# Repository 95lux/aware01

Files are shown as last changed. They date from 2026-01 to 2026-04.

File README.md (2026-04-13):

# Aarebot

> **Dynamic realtime stereo sampler for Eurorack modular synthesizer - STM32H7**

---

Aarebot is a dynamic realtime sampler built as a Eurorack module. At its core is a stereo tape-style engine with a hot-swapping record/playback buffer - this enables to record and play simultaneously.
Slicing markers can be added on the fly, and processing through an onboard effects chain.

Samplerate decimation trades fidelity for buffer length.
A Schroeder reverb implementation reaching from spacious room to sharp metallic resonance ringing depending on the XY effect mapping.

More DSP FX and taillred XY mapping is on the way and will turn Aarebot into an IDM LOFI crunch machine.

---
<p align="center">
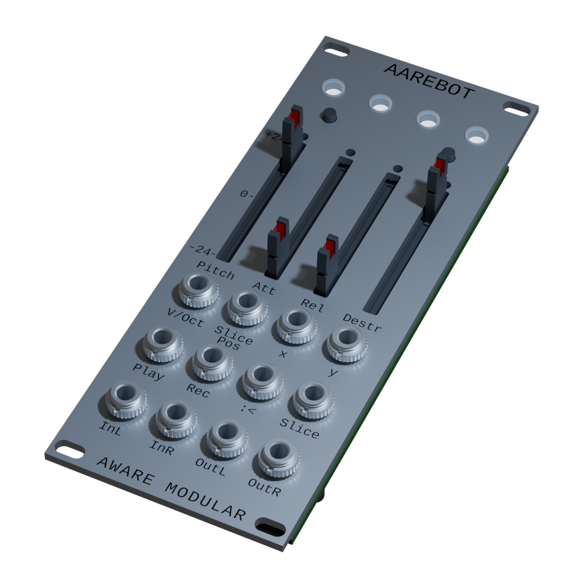
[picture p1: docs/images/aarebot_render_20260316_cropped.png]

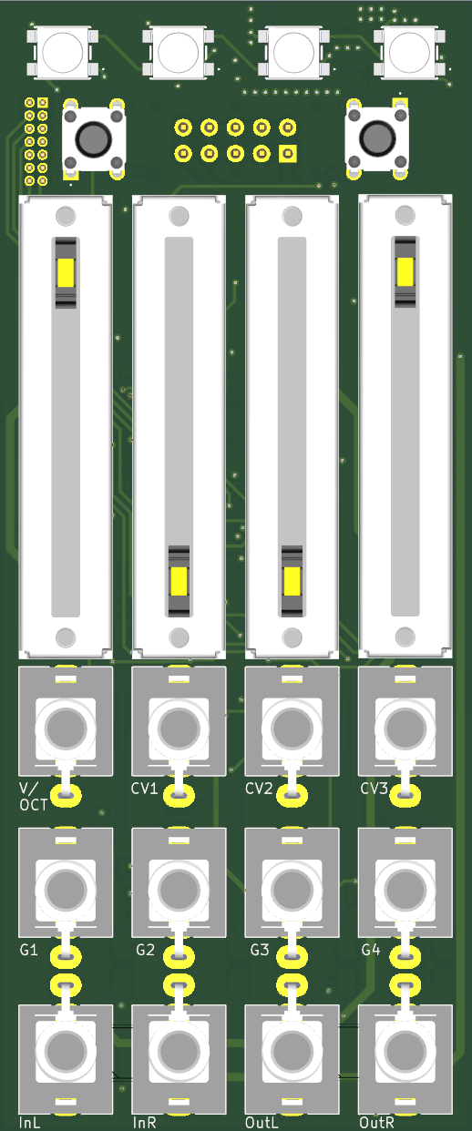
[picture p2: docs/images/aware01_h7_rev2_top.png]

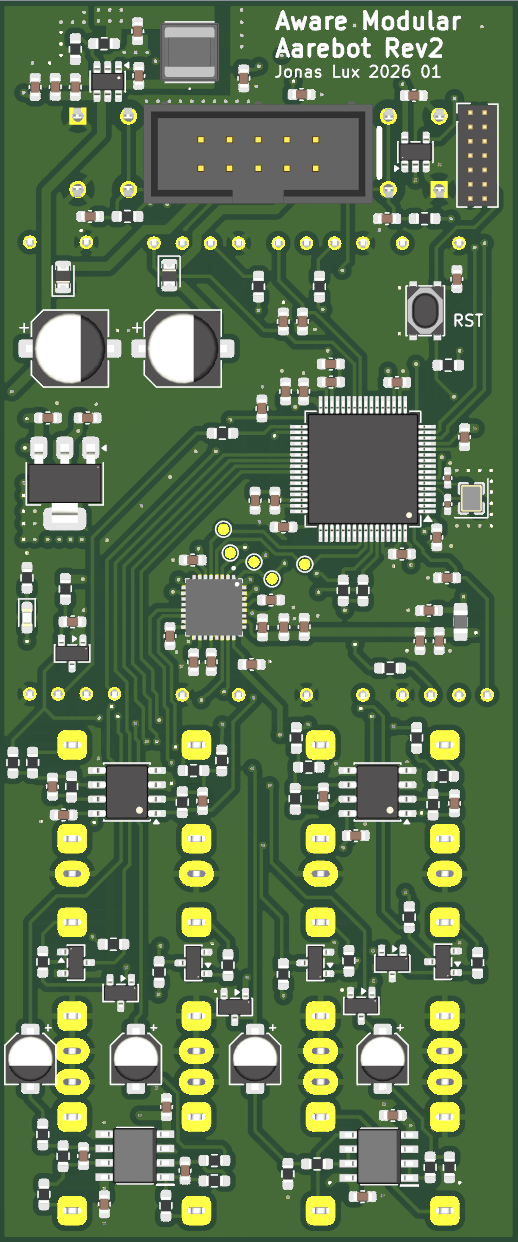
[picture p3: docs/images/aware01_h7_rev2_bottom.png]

</p>

## Features

### Audio Engine
- Stereo hot-swap record/playback buffer
- Realtime sample slicing with manual slice marker placement
- Hermite interpolation for smooth pitch shifting (±24 semitones)
- V/Oct pitch tracking (−1.5 V to +5 V)
- Samplerate decimation for extended recording time and lo-fi texture
- Nonlinear exciter
- Schroeder reverb with prime-length delay lines and scalable room size

### Control
| Interface | Function |
|---|---|
| Pot 1 | Base pitch (±24 semitones) |
| Pot 2 | Envelope attack |
| Pot 3 | Envelope decay / release |
| Pot 4 | Recording decimation |
| V/Oct | Pitch CV input |
| CV 2 | XY effect plane - X axis |
| CV 3 | XY effect plane - Y axis |
| Gate 1 | Record |
| Gate 2 | Play |
| Gate 3 | *(unassigned)* |
| Gate 4 | Set slice marker |

### Hardware
- STM32H7 MCU
- Custom I2C audio codec driver
- 4x WS2812 RGB LEDs for visual feedback
- ADC calibration with 2-point and piecewise CV calibration
- Full KiCad schematic and PCB design
- SPICE simulations for analog input/output stages

---

## Repository Structure

```
├── firmware/                 STM32CubeMX project and C source
|   ├── Aware                 Main firmware implementation
|   └── Src                   CubeMX generated src files
├── hardware/
│   ├── aware01_h7_rev2_0/    KiCad schematic and PCB
│   └── simulation/           SPICE simulations for analog stages
└── docs/
    ├── images/               PCB renders and oscilloscope captures
    ├── ba/                   Bachelor thesis
    │   ├── latex/            LaTeX source files
    │   ├── images/           Figures and plots
    │   ├── diagrams/         DrawIO block diagrams
    │   └── scripts/          Python scripts for analysis and plots
    └── project_management/   Project planning documents
        ├── lastenheft.tex    Requirements specification
        ├── pflichtenheft.tex Functional specification
        └── projectplan.tex   Project plan
```

---

## Building

### Dependencies

| Tool | Arch | Debian/Ubuntu |
|---|---|---|
| ARM cross-compiler | `arm-none-eabi-gcc` | `gcc-arm-none-eabi` |
| ARM newlib | `arm-none-eabi-newlib` | `libnewlib-arm-none-eabi` |
| CMake ≥ 3.22 | `cmake` | `cmake` |
| Ninja | `ninja` | `ninja-build` |

### Compile

```sh
cd firmware

# Configure + build (Debug)
cmake --preset Debug
cmake --build --preset Debug

# Configure + build (Release)
cmake --preset Release
cmake --build --preset Release
```

The output ELF is at `firmware/build/Debug/firmware.elf`.

### Flash

Requires an ST-Link probe. Either `st-flash` (stlink) or `openocd` can be used.

**openocd** (recommended; works directly with ELF):

```sh
openocd -f interface/stlink.cfg -f target/stm32h7x.cfg \
  -c "program firmware/build/Debug/firmware.elf verify reset exit"
```

**st-flash** (requires converting ELF to binary first):

```sh
arm-none-eabi-objcopy -O binary \
  firmware/build/Debug/firmware.elf \
  firmware/build/Debug/firmware.bin

st-flash write firmware/build/Debug/firmware.bin 0x8000000
```

| Tool | Arch | Debian/Ubuntu |
|---|---|---|
| openocd | `openocd` | `openocd` |
| st-flash | `stlink` | `stlink-tools` |

---

## Hardware

Designed in KiCad. The hardware directory contains the full schematic, PCB layout, and SPICE simulations for the analog input and output conditioning stages.

### KiCad Library

Opening the KiCad project requires the custom component library. Clone it alongside this repo:

```sh
git clone https://github.com/95lux/kicad_library
```

Then add it as a global library in KiCad: **Preferences → Manage Symbol Libraries** (and **Manage Footprint Libraries**), pointing to the cloned directory.

---

## Specifications

### Audio
| Parameter | Value |
|---|---|
| Sample rate | 48 kHz |
| Bit depth | 16-bit |
| Recording buffer | 2.5 s (stereo) |
| End-to-end latency | ~1.9 ms |
| Audio codec | TLV320AIC3204 |

### Hardware
| Parameter | Value |
|---|---|
| MCU | STM32H7A3RITx (Cortex-M7, 280 MHz) |
| Form factor | 10 HP, 3U Eurorack |
| Audio I/O levels | ±5 V |
| CV input range | ±10 V |
| V/Oct range | −1.5 V to +5 V |
| Power (+12V) | ~80 mA idle, ~140 mA peak |
| Power (−12V) | ~20 mA |

---

## License

| Component | License |
|---|---|
| Firmware / software | [GPL-3.0](LICENSE) |
| Hardware (schematics, PCB, SPICE) | [CERN OHL-S v2](LICENSE-CERN-OHL-S) |
| Thesis / documentation | [CC BY 4.0](LICENSE-CC-BY) |

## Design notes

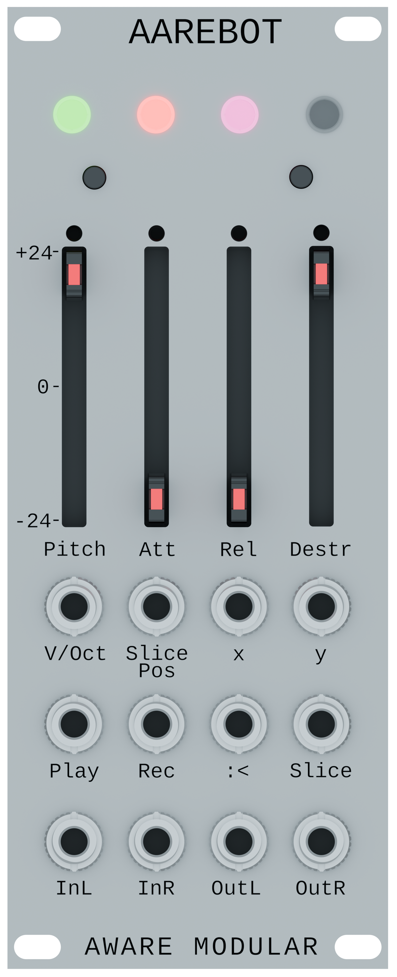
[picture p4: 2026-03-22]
hardware/panel_design/blender_render/aarebot_render_topdown_20260321.png

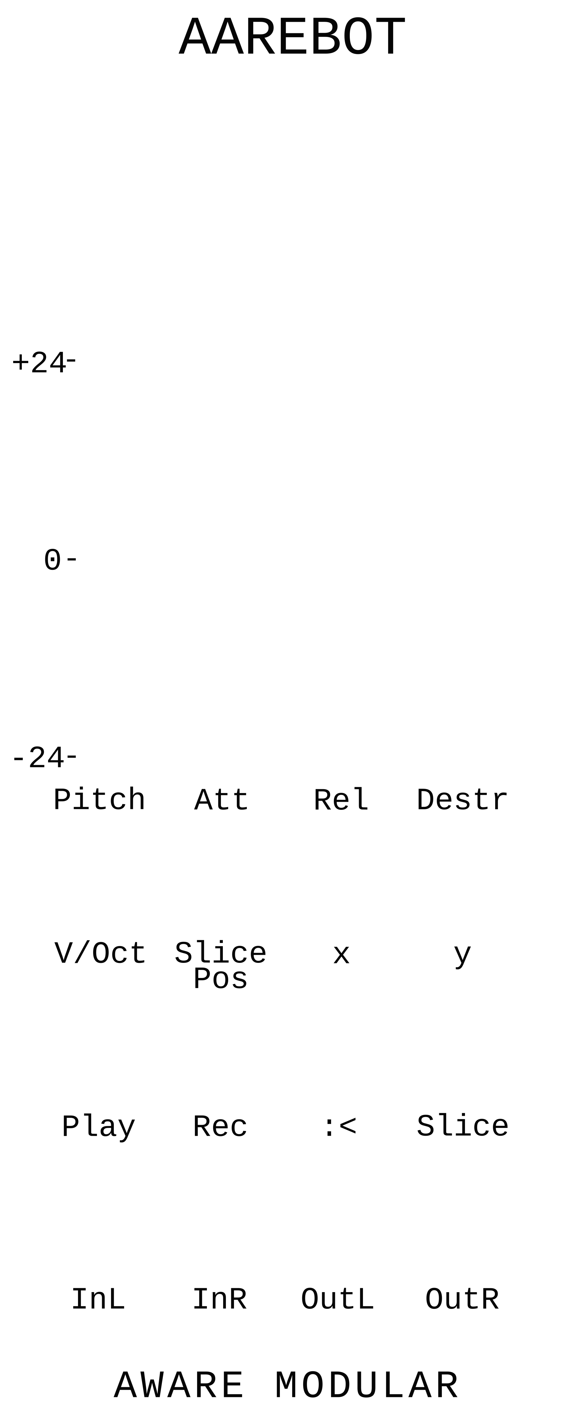
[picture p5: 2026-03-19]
hardware/panel_design/design/export/panel_font_only_texture.png

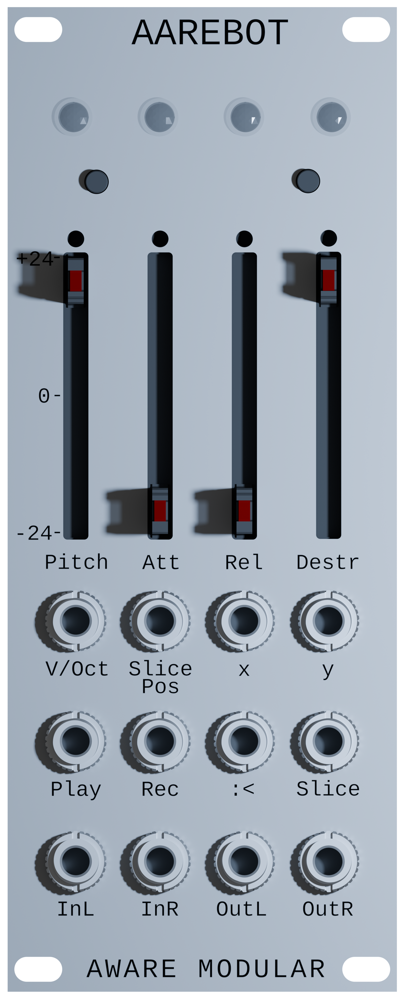
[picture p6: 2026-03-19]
hardware/panel_design/blender_render/aarebot_render_topdown_20260316.png

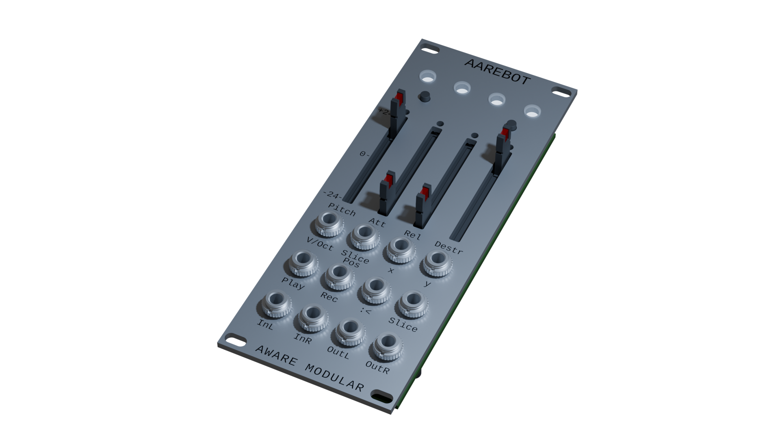
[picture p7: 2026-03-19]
hardware/panel_design/blender_render/aarebot_render_20260316.png

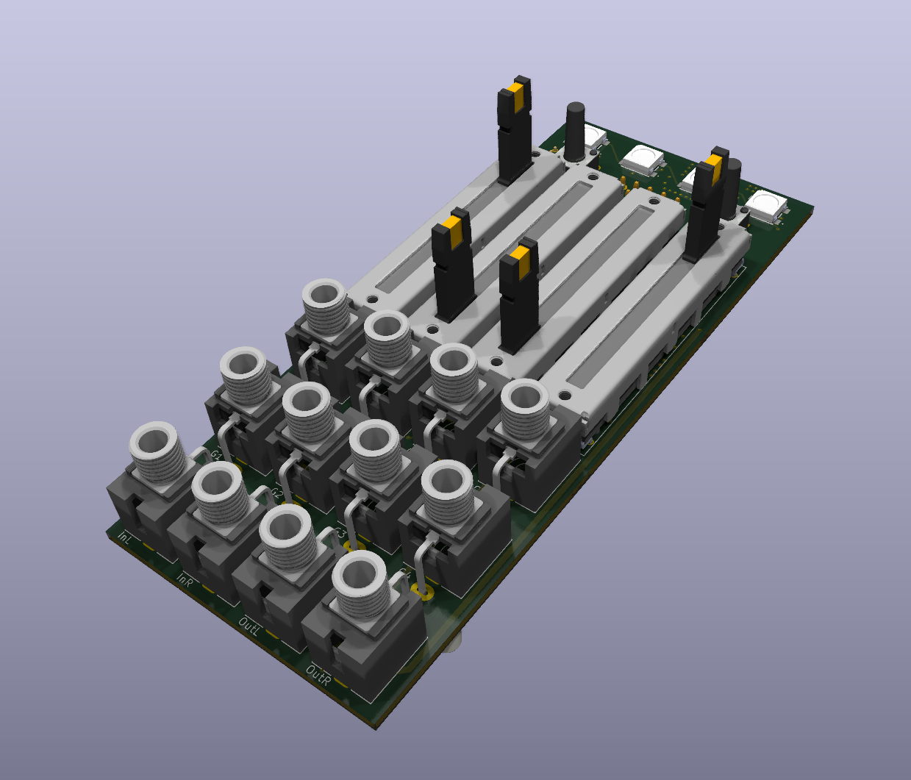
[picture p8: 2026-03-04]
docs/images/aware01_h7_rev2.png

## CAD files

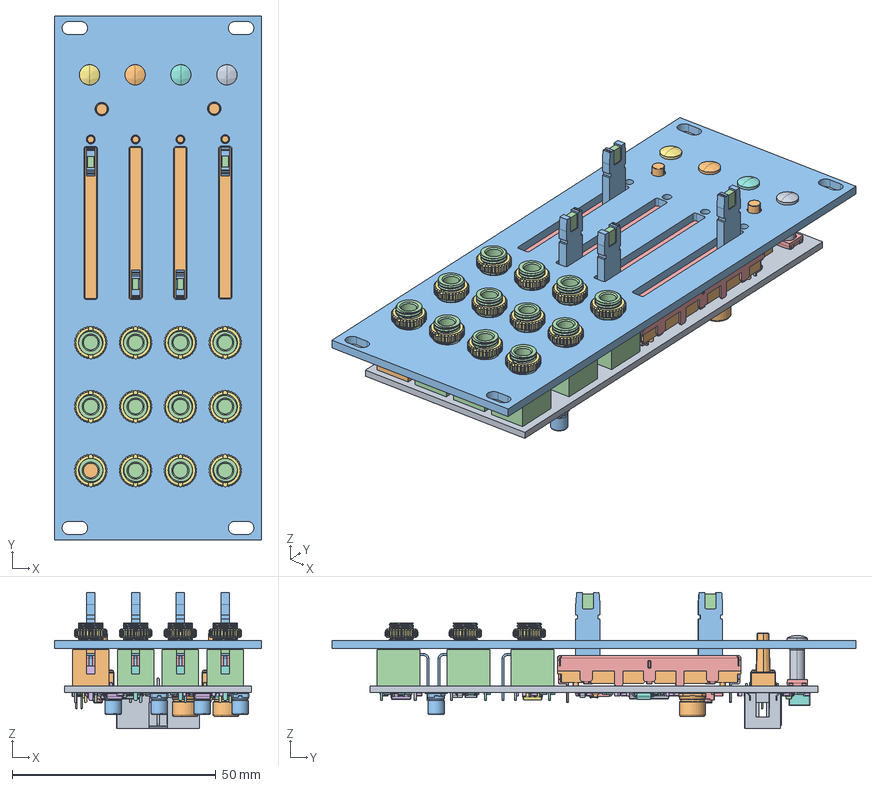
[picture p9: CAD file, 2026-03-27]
hardware/panel_design/freecad/aware01_h7_rev2_0_panel.FCStd
50.8 x 128.5 x 33.4 mm
Pcb_9190
S002 x 12
Hole002 x 12
TN002 x 12
T002 x 12
Knurl_nut x 12
T x 11
TN x 11
Hole x 11
S x 11
IC4_587-2054-127F_e23b30a79e93 x 4
CUI_DEVICES_TS02-66-130-BK-160-LCR-D x 2
CUI_DEVICES_TS02-66-130-BK-160-LCR-D001 x 2
CUI_DEVICES_TS02-66-130-BK-160-LCR-D002 x 2
CUI_DEVICES_TS02-66-130-BK-160-LCR-D003 x 2
CUI_DEVICES_TS02-66-130-BK-160-LCR-D004 x 2
CUI_DEVICES_TS02-66-130-BK-160-LCR-D005 x 2
PTL30-15A1-102B1 x 4
PTL30-15A1-102B002 x 4
PTL30-15A1-102B003 x 4
PTL30-15A1-102B004 x 4
PTL30-15A1-102B005 x 4
PTL30-15A1-102B006 x 4
PTL30-15A1-102B007 x 4
PTL30-15A1-102B008 x 4
PTL30-15A1-102B009 x 4
PTL30-15A1-102B010 x 4
C2_C_0603_1608Metric_e7f1de577f97 x 53
U12_SOIC-8_3.9x4.9mm_P1.27mm_2611bc220bab x 2
R31_R_0603_1608Metric_75cdd0927c24 x 43
D5_SOT-23_d05a828cb339 x 9
C15_CP_Elec_63x59_83b6301a71eb x 2
C17_C_0402_1005Metric_89bd16c9ed12 x 2
J1_PinHeader_2x07_P127mm_Vertical_6e9aa3e86ace
D2_D_0805_316b401283b4 x 2
BODY-SO x 2
LEAD-D0008A x 2
LEAD-D0008A001 x 2
LEAD-D0008A002 x 2
LEAD-D0008A003 x 2
LEAD-D0008A004 x 2
LEAD-D0008A005 x 2
LEAD-D0008A006 x 2
LEAD-D0008A007 x 2
FB1_L_0805_2012Metric_155c62dd4ffa
U2_SOT-223_d1530b612a2a
J2_BHR-10-VUA_f9be22c26796
D1_LED_0603_1608Metric_f8b77dac1ffc
C52_CP_Elec_4x54_ea18e54b4708 x 4
U1_SOT-23-6_937026b9fb56
SW3_SW_SPST_PTS810_bbe2ddf1a39a
SRR5228A-3R3Y
SRR5228A-3R3Y001
SRR5228A-3R3Y002
U4_LQFP-64_10x10mm_P0.5mm_12fefaba2387
Y1_Crystal_SMD_2520-4Pin_2.5x2.0mm_2624cf7f43d5
TPS40322RHBT
TPS40322RHBT001
TPS40322RHBT002
TPS40322RHBT003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

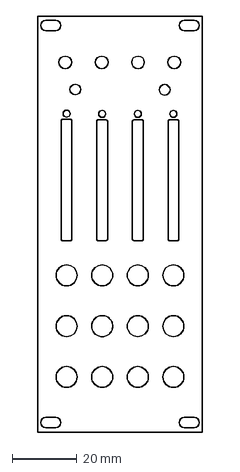
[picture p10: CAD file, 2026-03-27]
hardware/panel_design/freecad/export/panel_outline_cutouts.dxf
50.8 x 128.5 mm

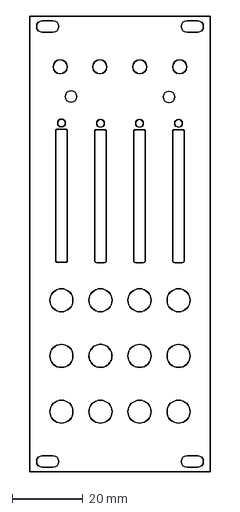
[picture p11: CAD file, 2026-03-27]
hardware/panel_design/freecad/export/panel_freecad_26-03-27.dxf
50.8 x 128.5 mm

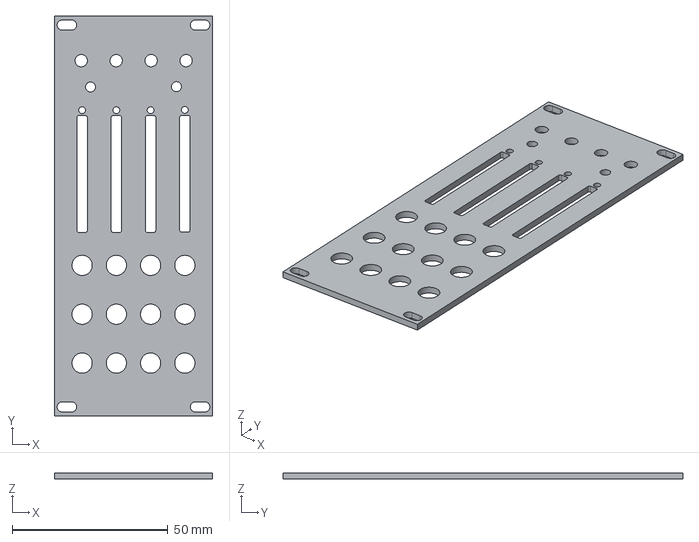
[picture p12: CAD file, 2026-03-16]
hardware/panel_design/freecad/export/aware01_h7_rev2_0_panel-Faceplate.step
50.8 x 128.5 x 2.00 mm

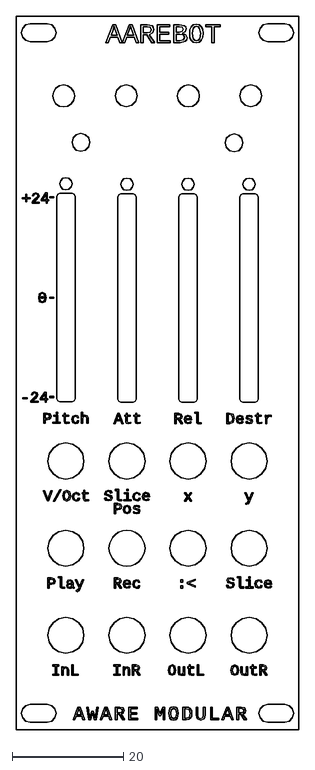
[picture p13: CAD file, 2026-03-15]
hardware/panel_design/freecad/export/panel.dxf
50.8 x 128.5

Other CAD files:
hardware/panel_design/freecad/export/aware01_h7_rev2_0_pcb_only.obj
hardware/panel_design/freecad/export/aware01_h7_rev2_0_pcb_and_panel.obj
hardware/panel_design/blender_render/panel.blend

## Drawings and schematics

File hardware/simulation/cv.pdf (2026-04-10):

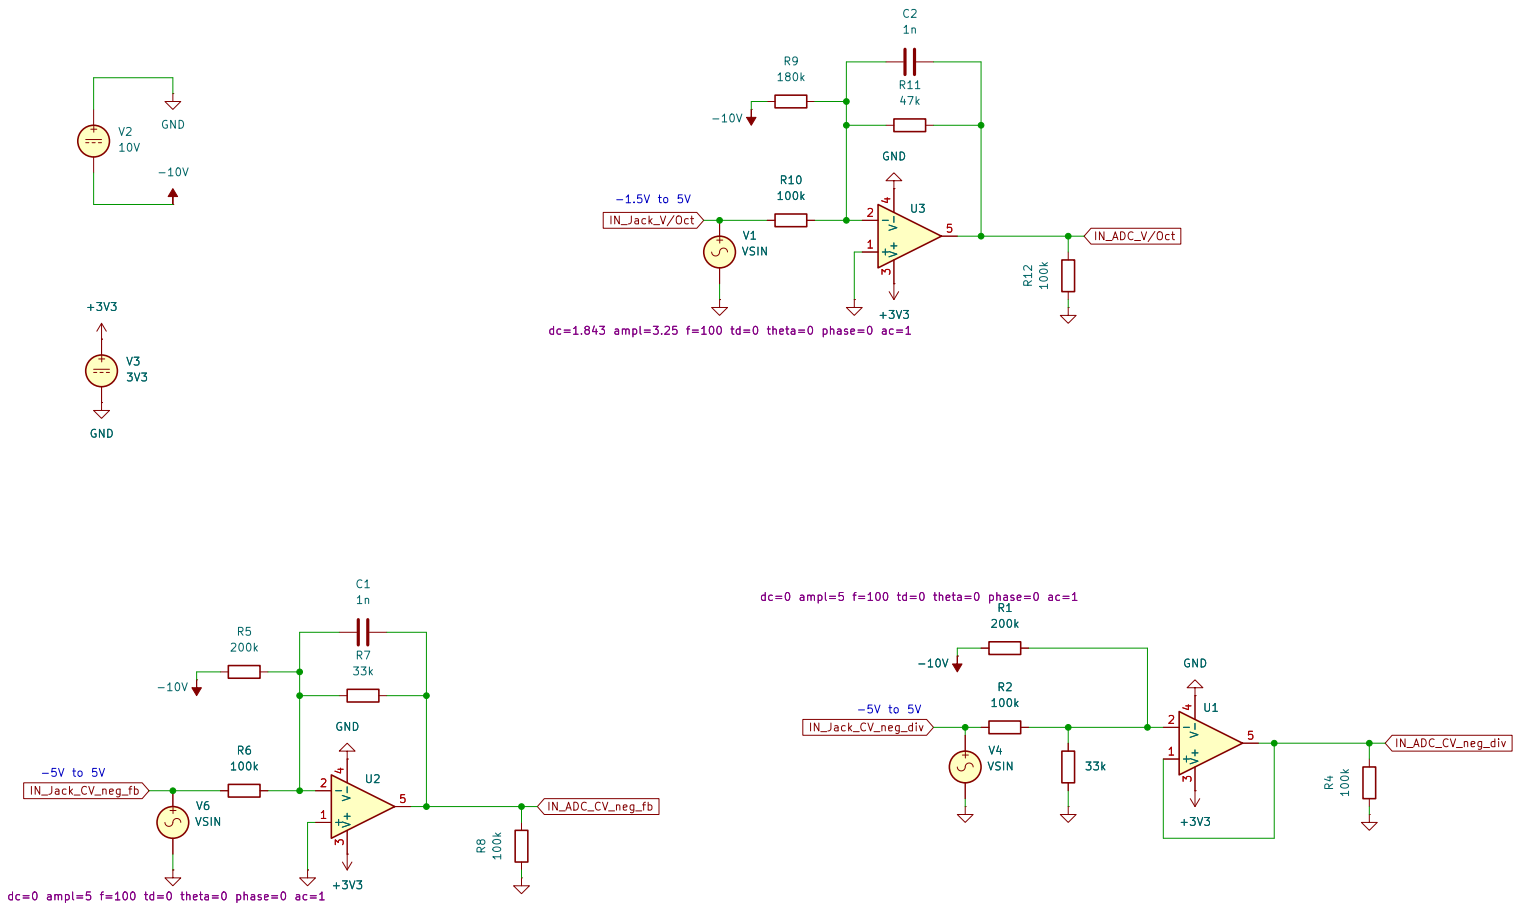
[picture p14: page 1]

dc=1.843 ampl=3.25 f=100 td=0 theta=0 phase=0 ac=1 +3V3 R6

dc=1.843 ampl=3.25 f=100 td=0 theta=0 phase=0 ac=1

dc=0 ampl=5 f=100 td=0 theta=0 phase=0 ac=1 R2

dc=0 ampl=5 f=100 td=0 theta=0 phase=0 ac=1 GND

dc=0 ampl=5 f=100 td=0 theta=0 phase=0 ac=1

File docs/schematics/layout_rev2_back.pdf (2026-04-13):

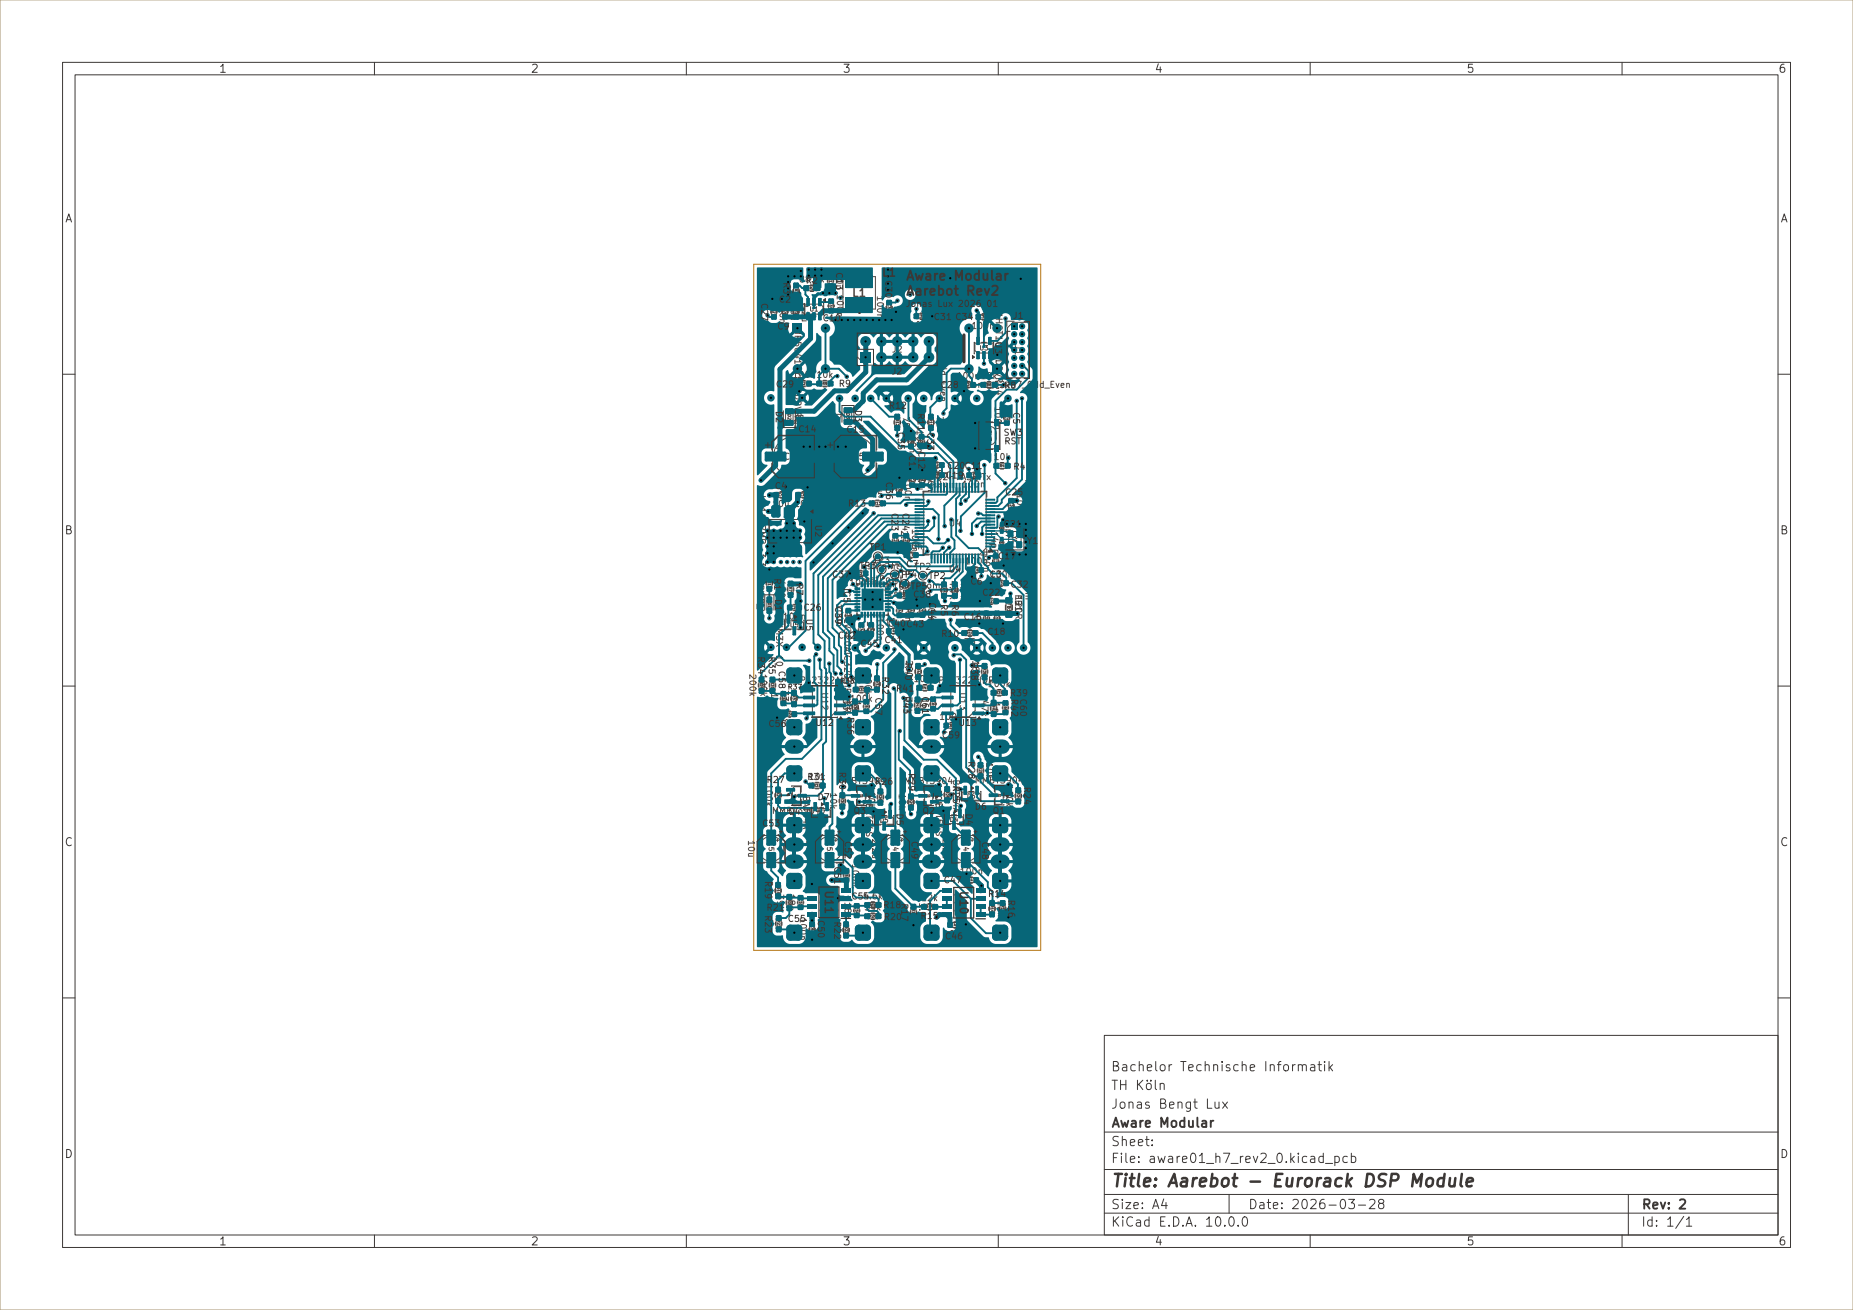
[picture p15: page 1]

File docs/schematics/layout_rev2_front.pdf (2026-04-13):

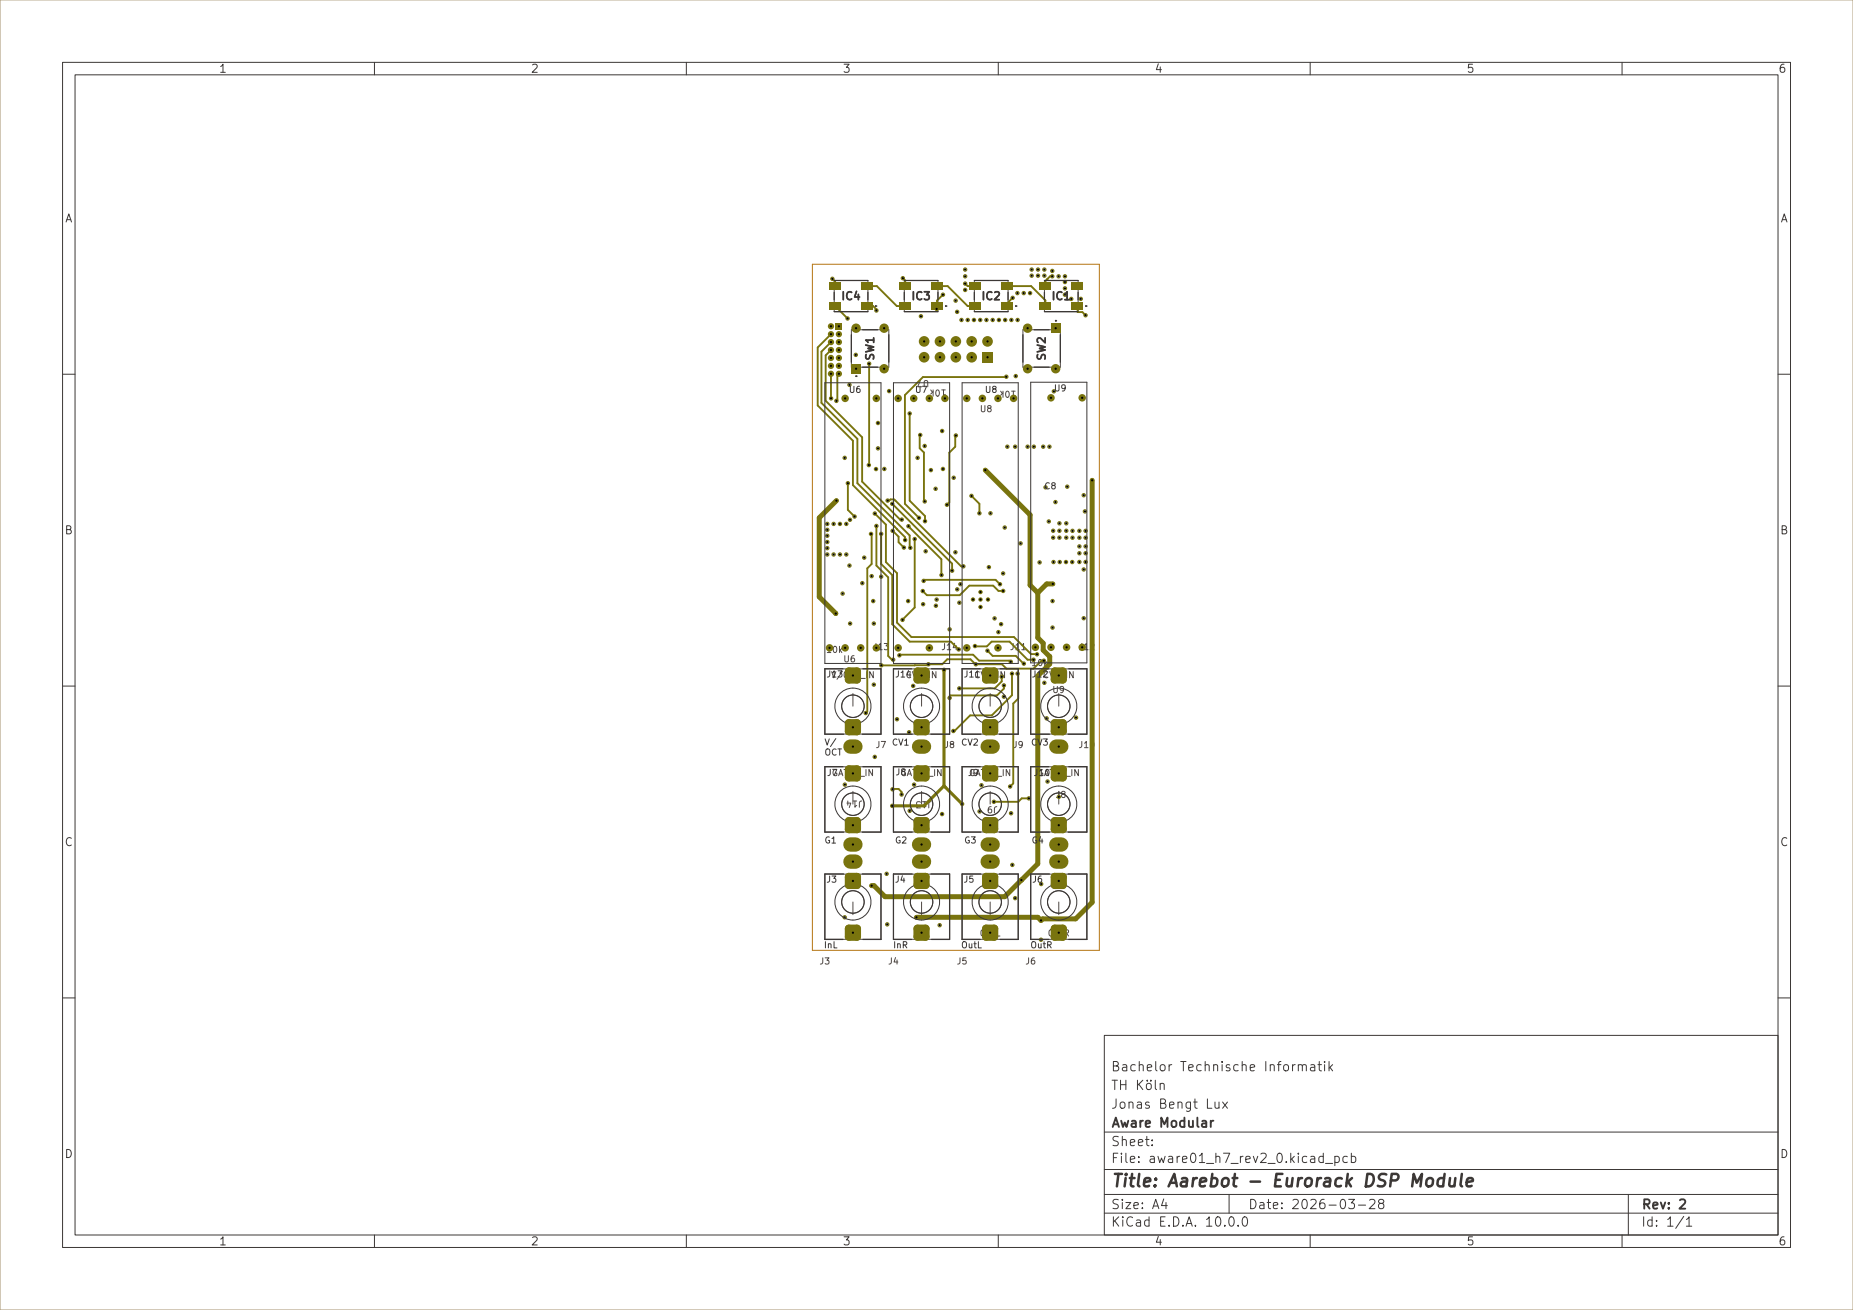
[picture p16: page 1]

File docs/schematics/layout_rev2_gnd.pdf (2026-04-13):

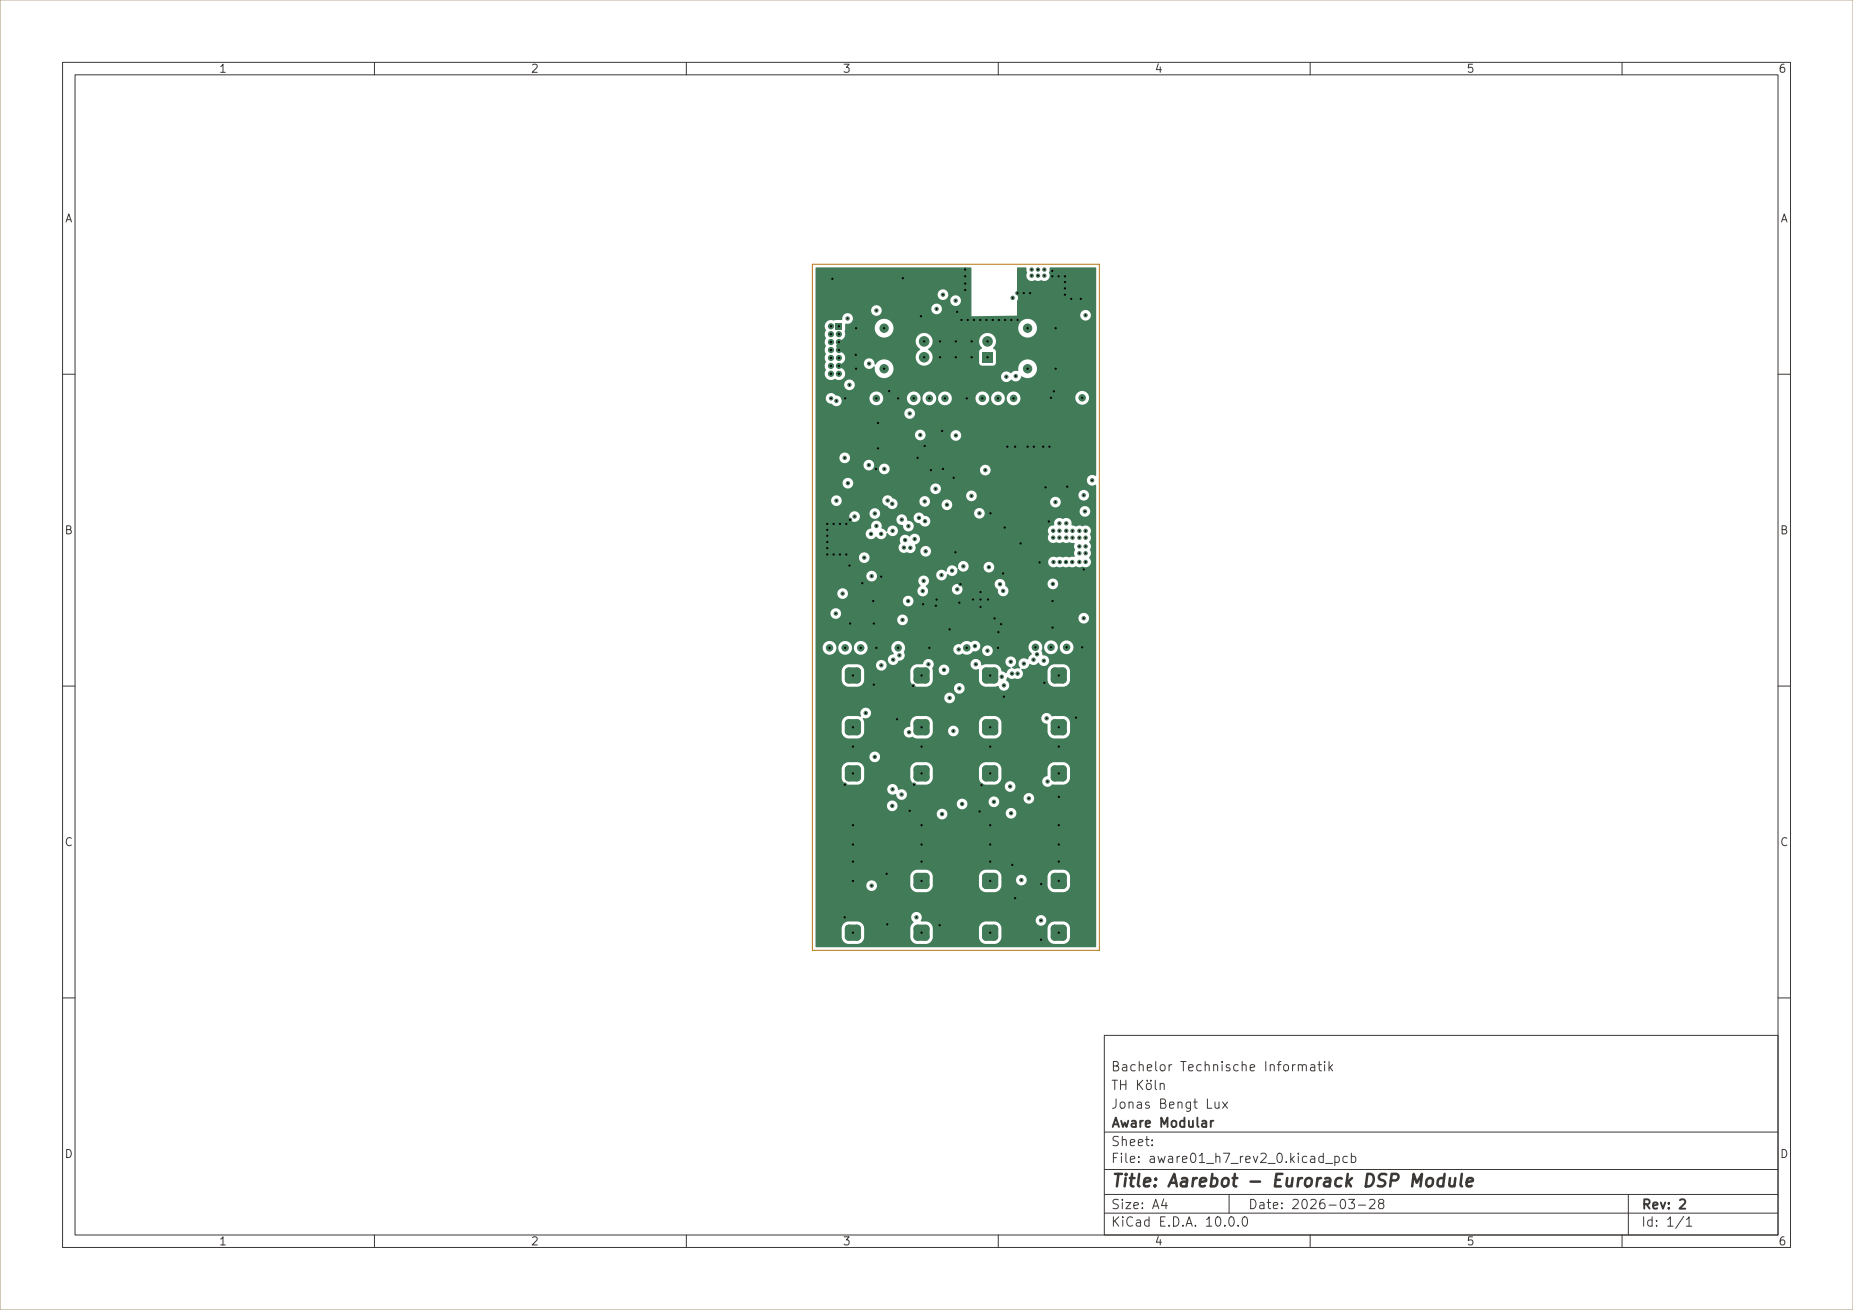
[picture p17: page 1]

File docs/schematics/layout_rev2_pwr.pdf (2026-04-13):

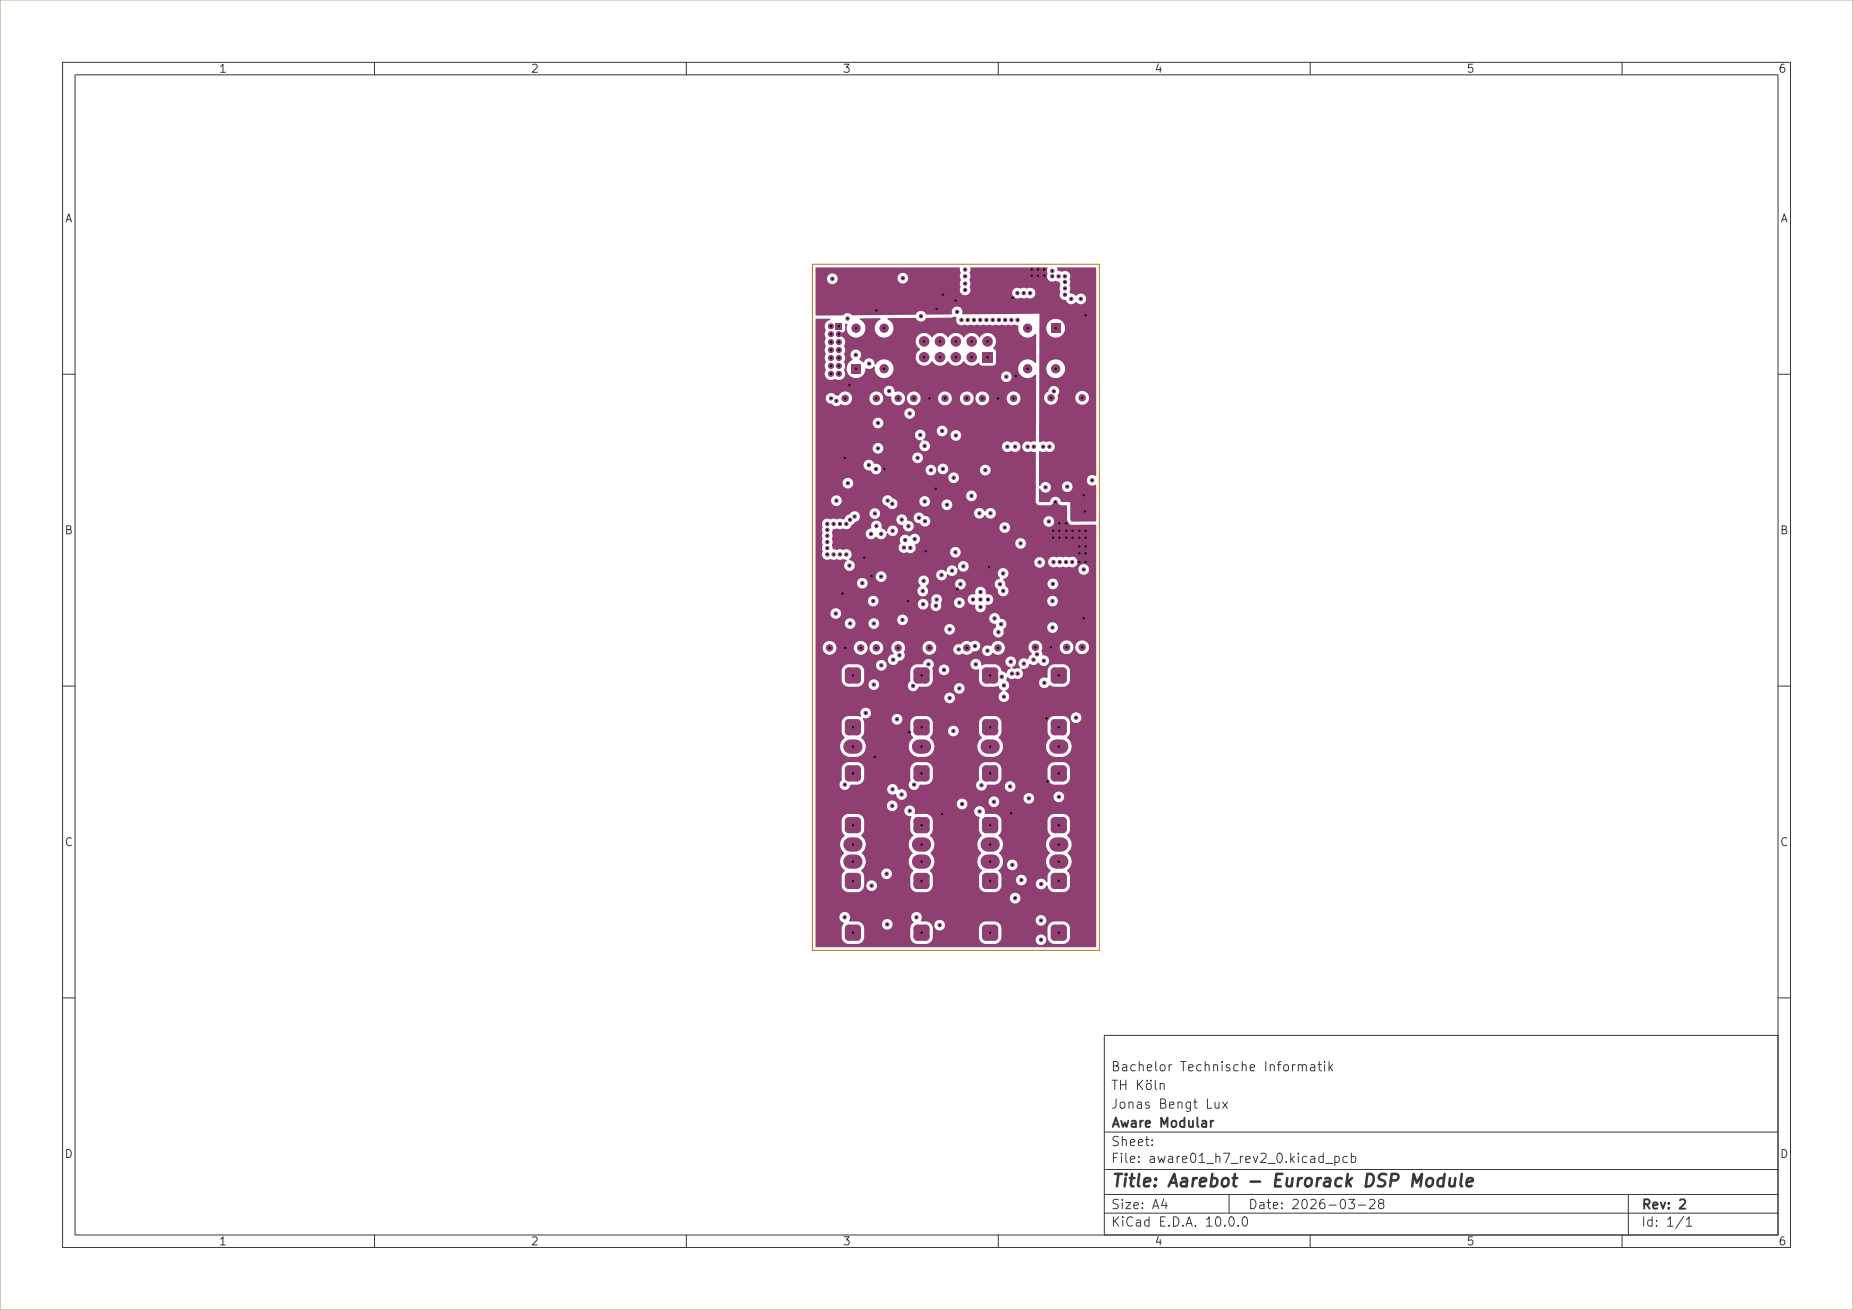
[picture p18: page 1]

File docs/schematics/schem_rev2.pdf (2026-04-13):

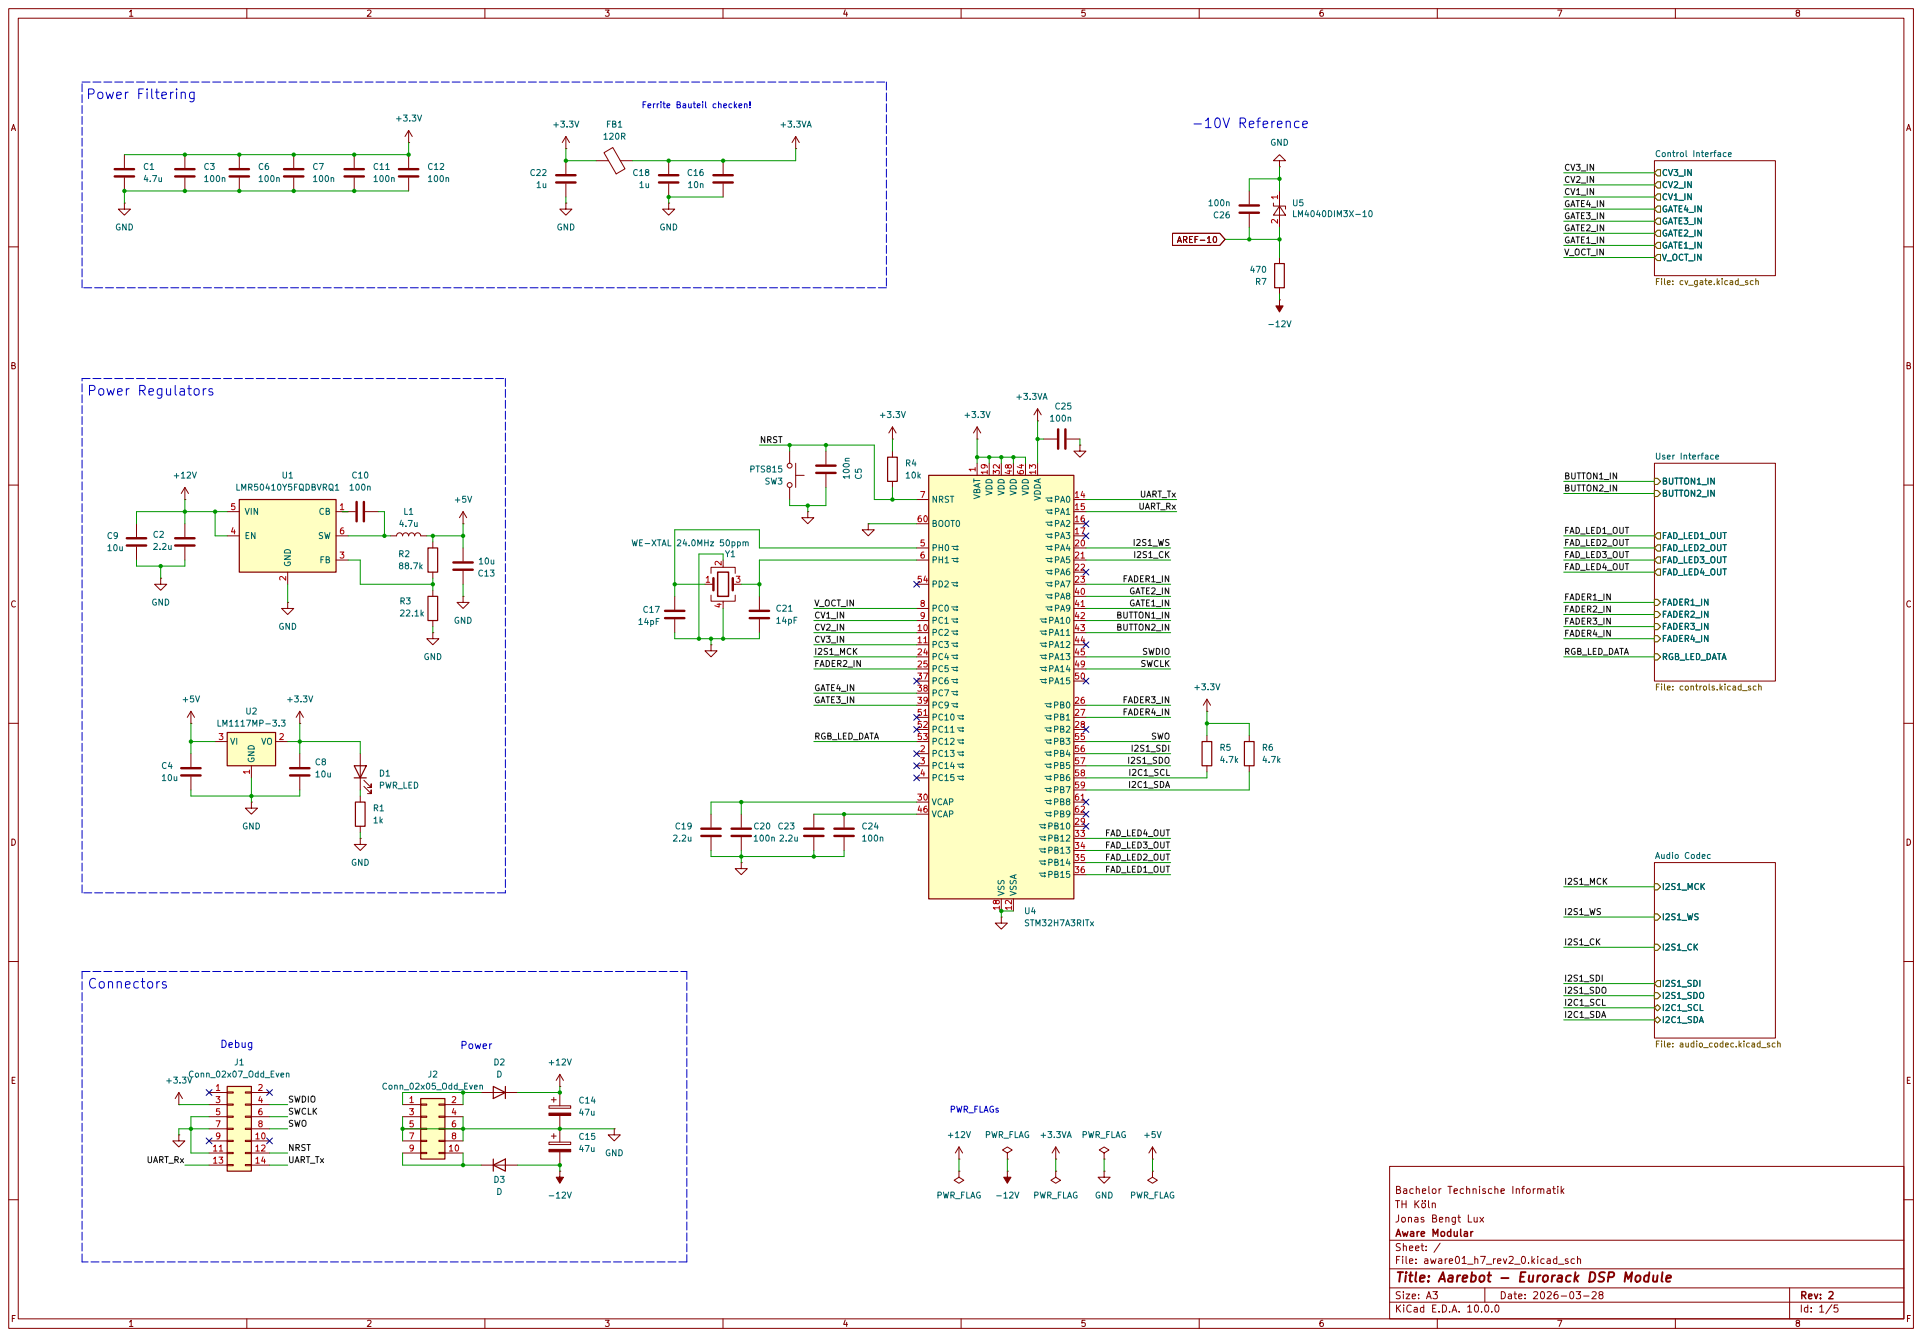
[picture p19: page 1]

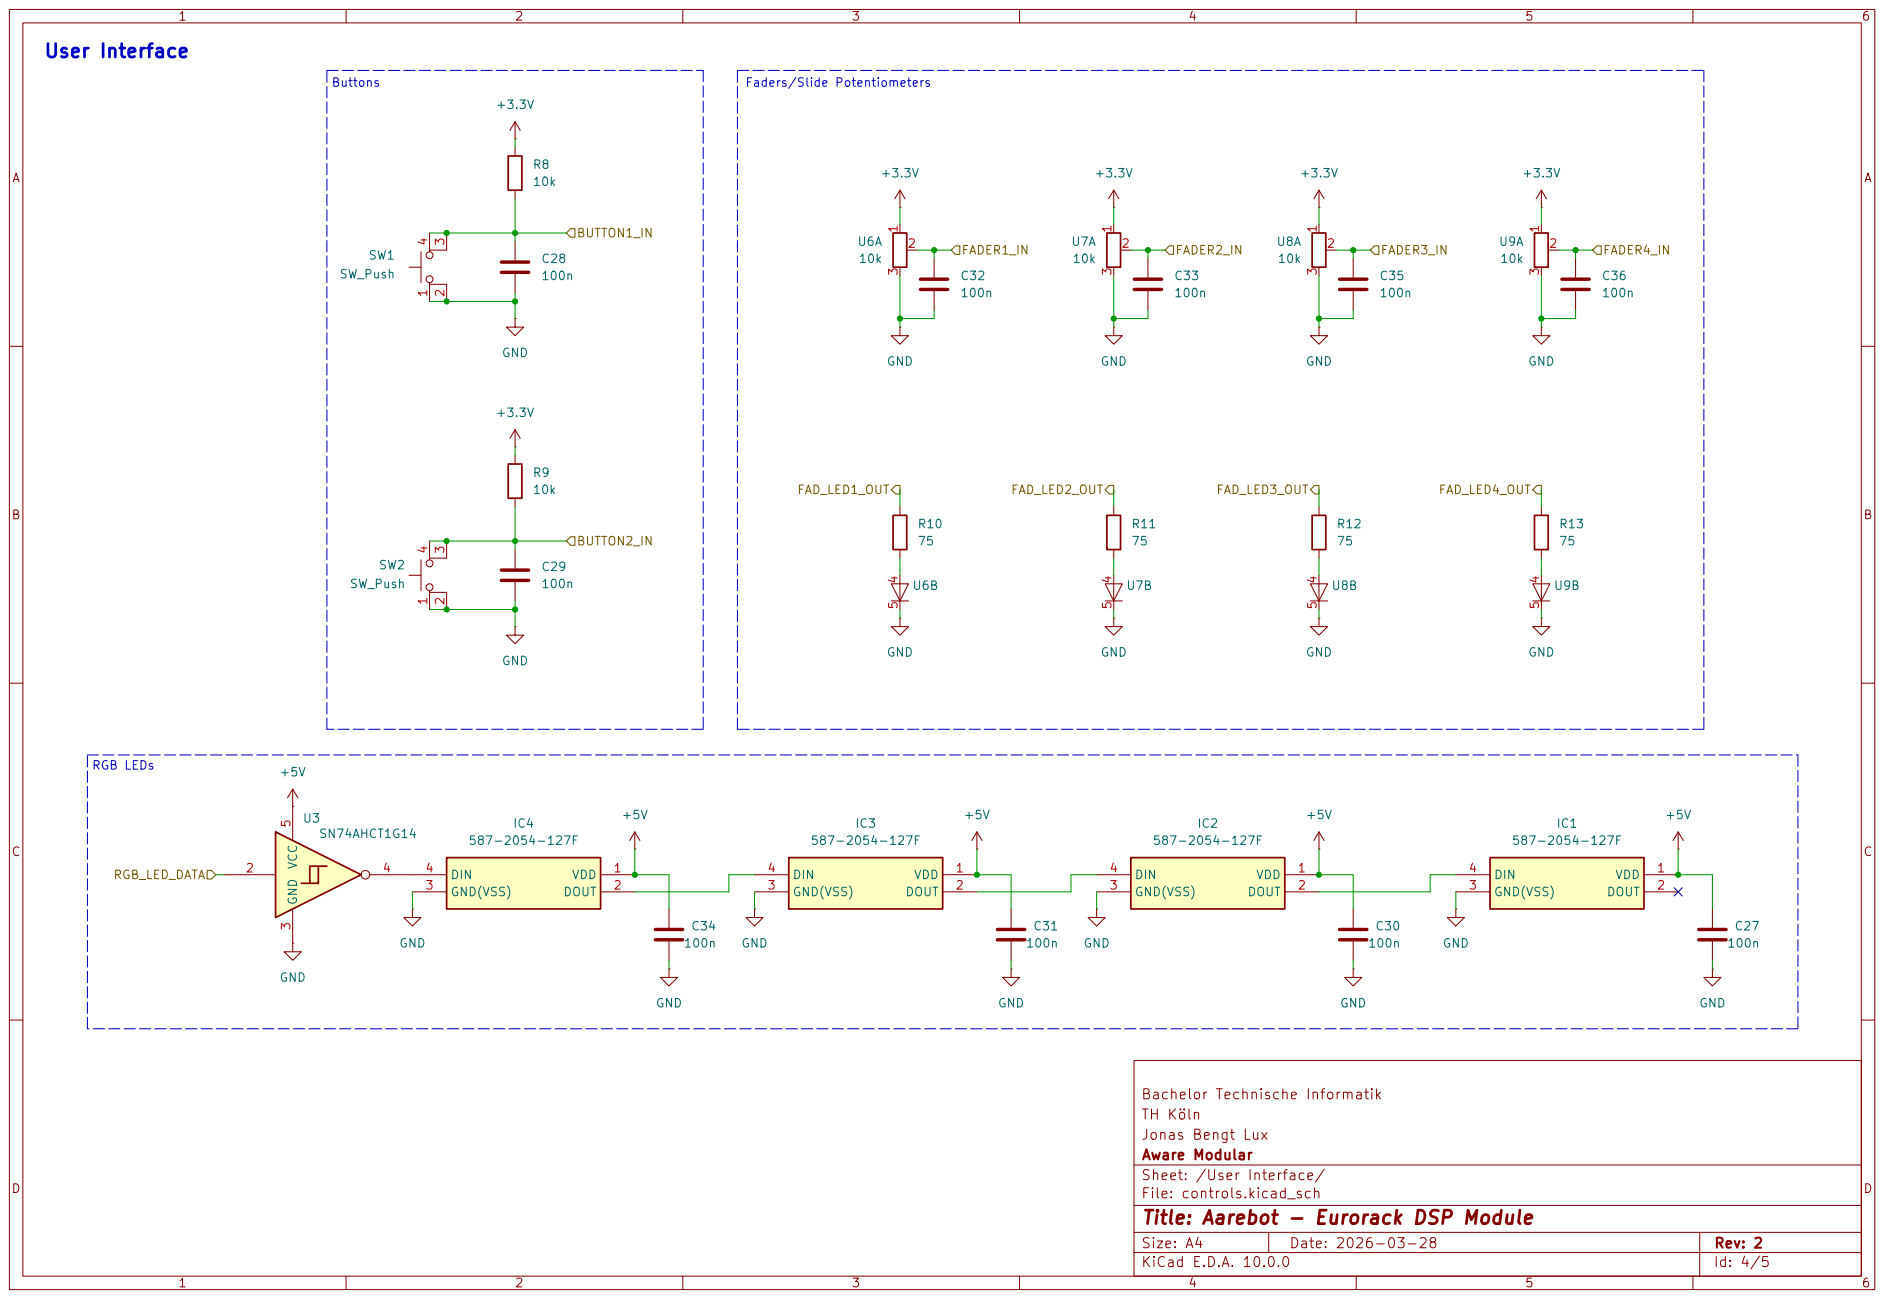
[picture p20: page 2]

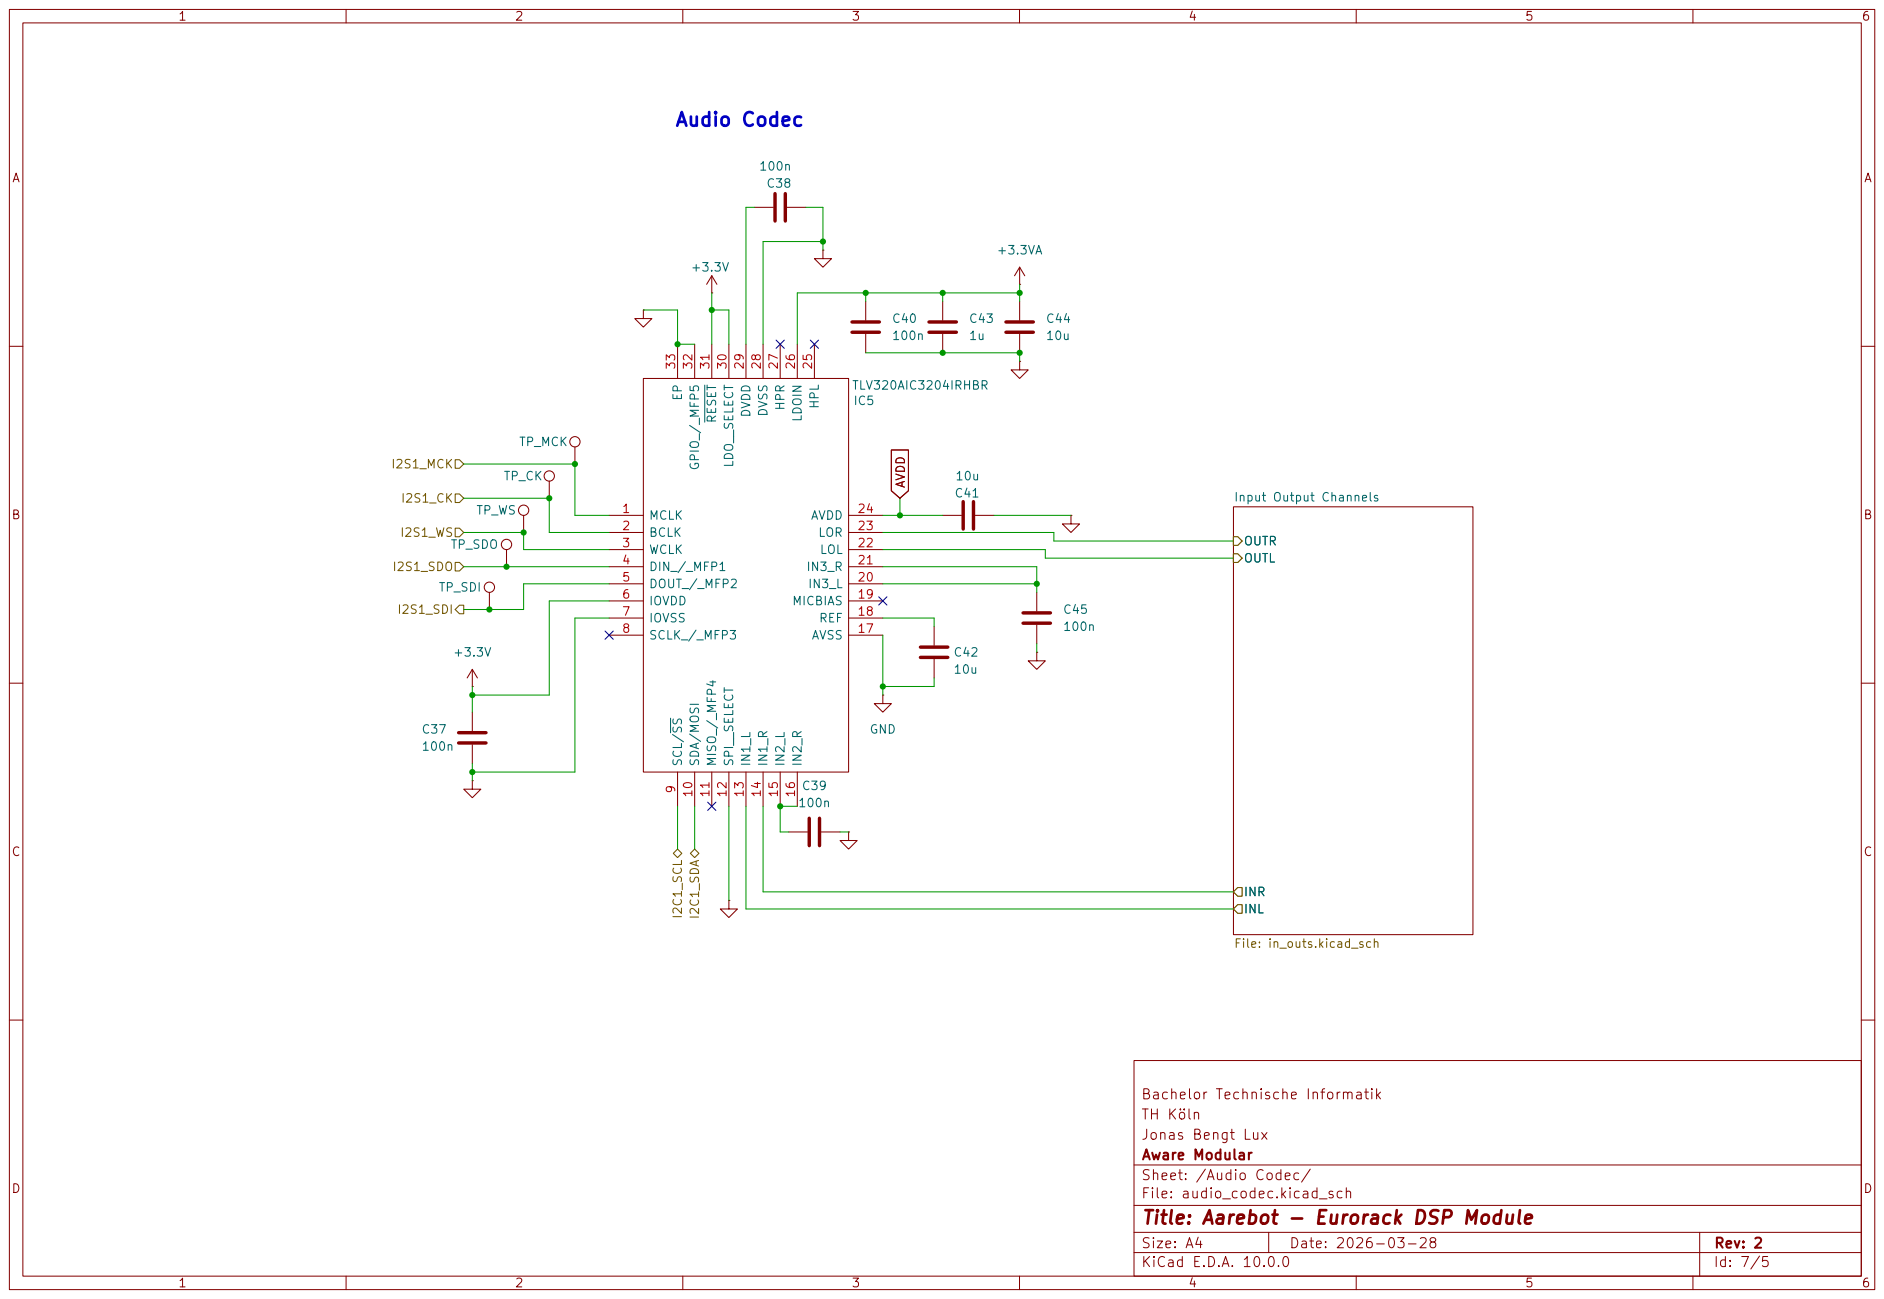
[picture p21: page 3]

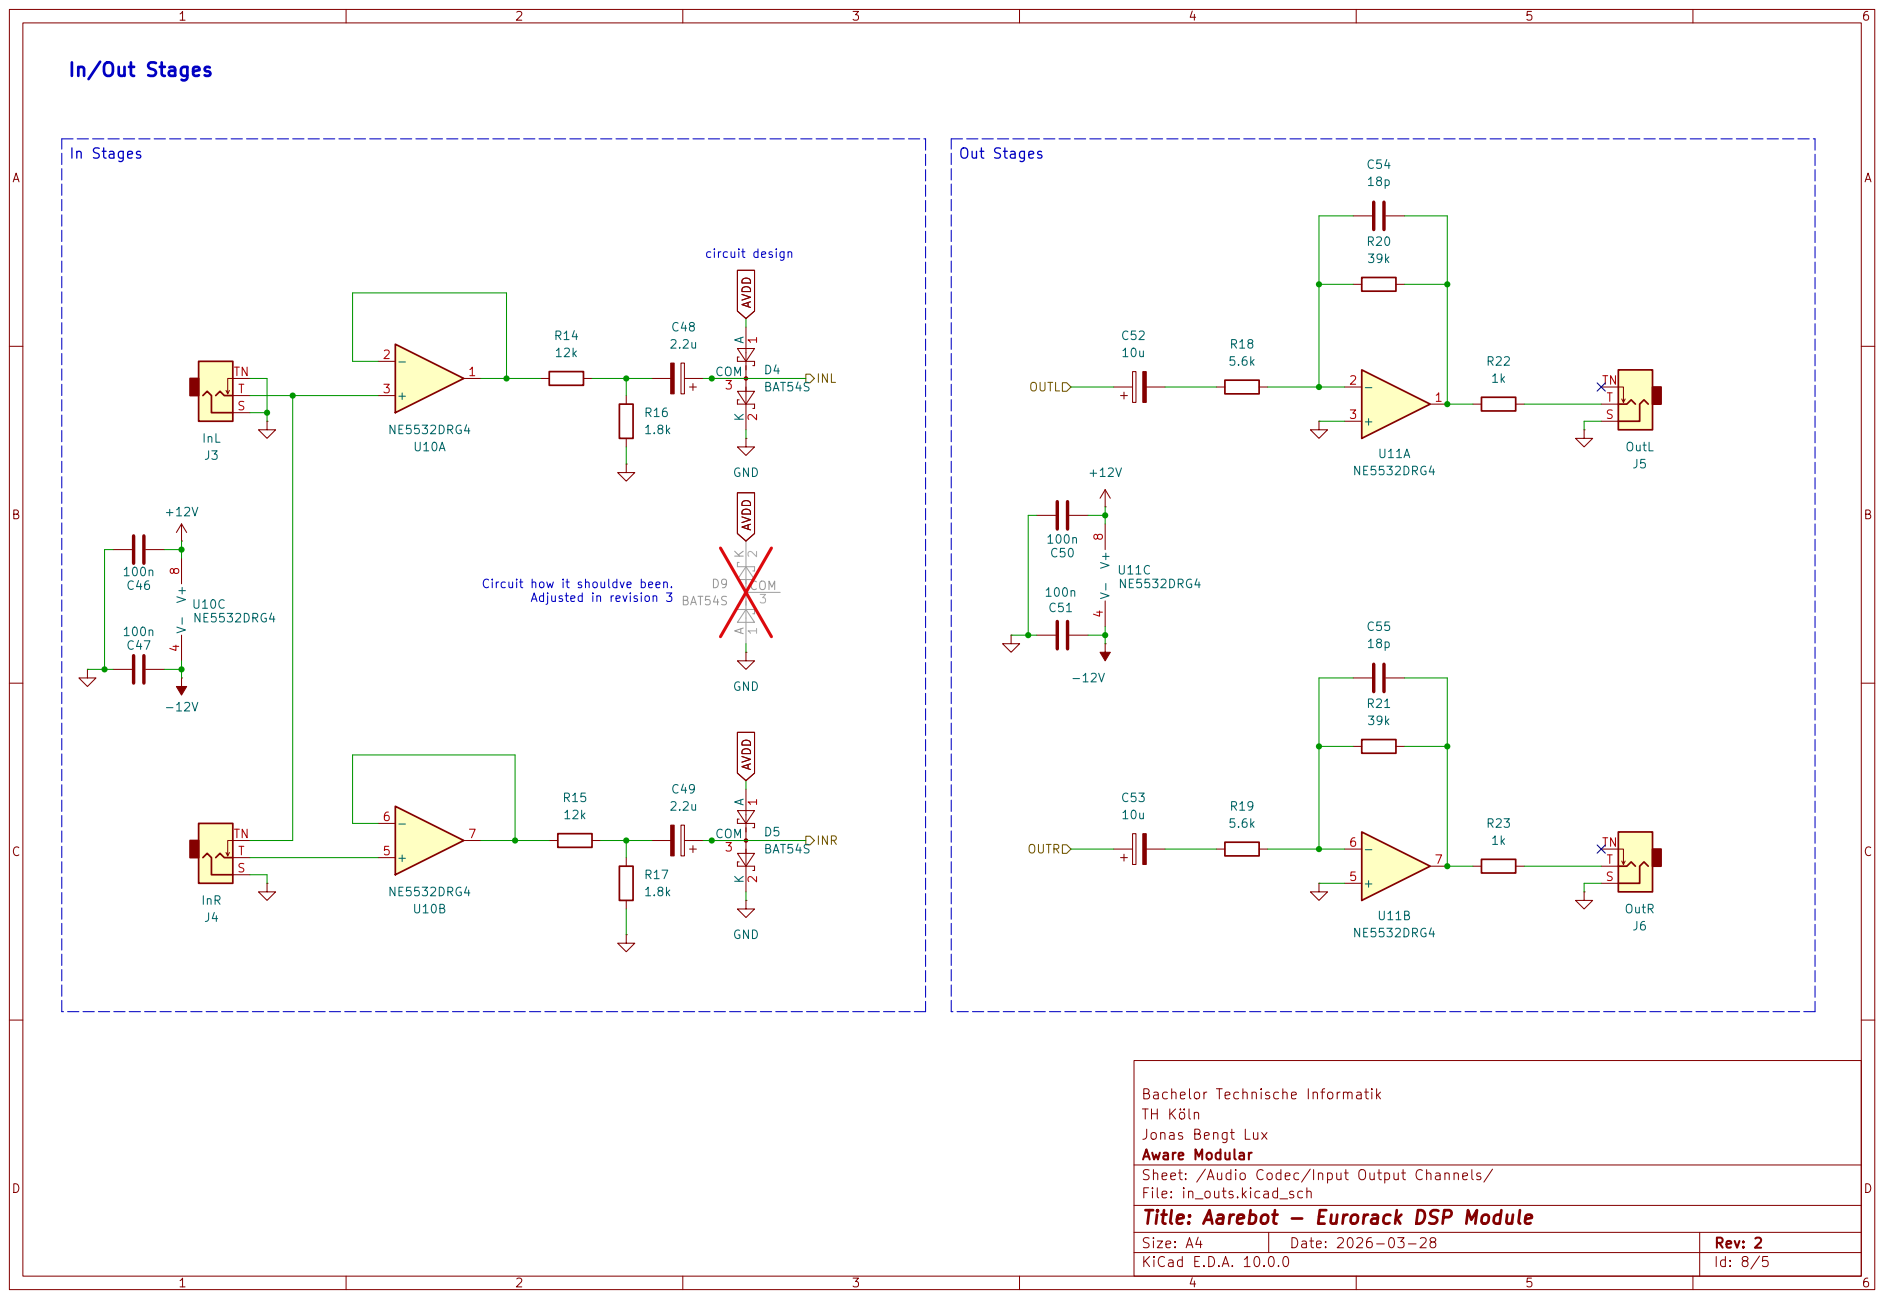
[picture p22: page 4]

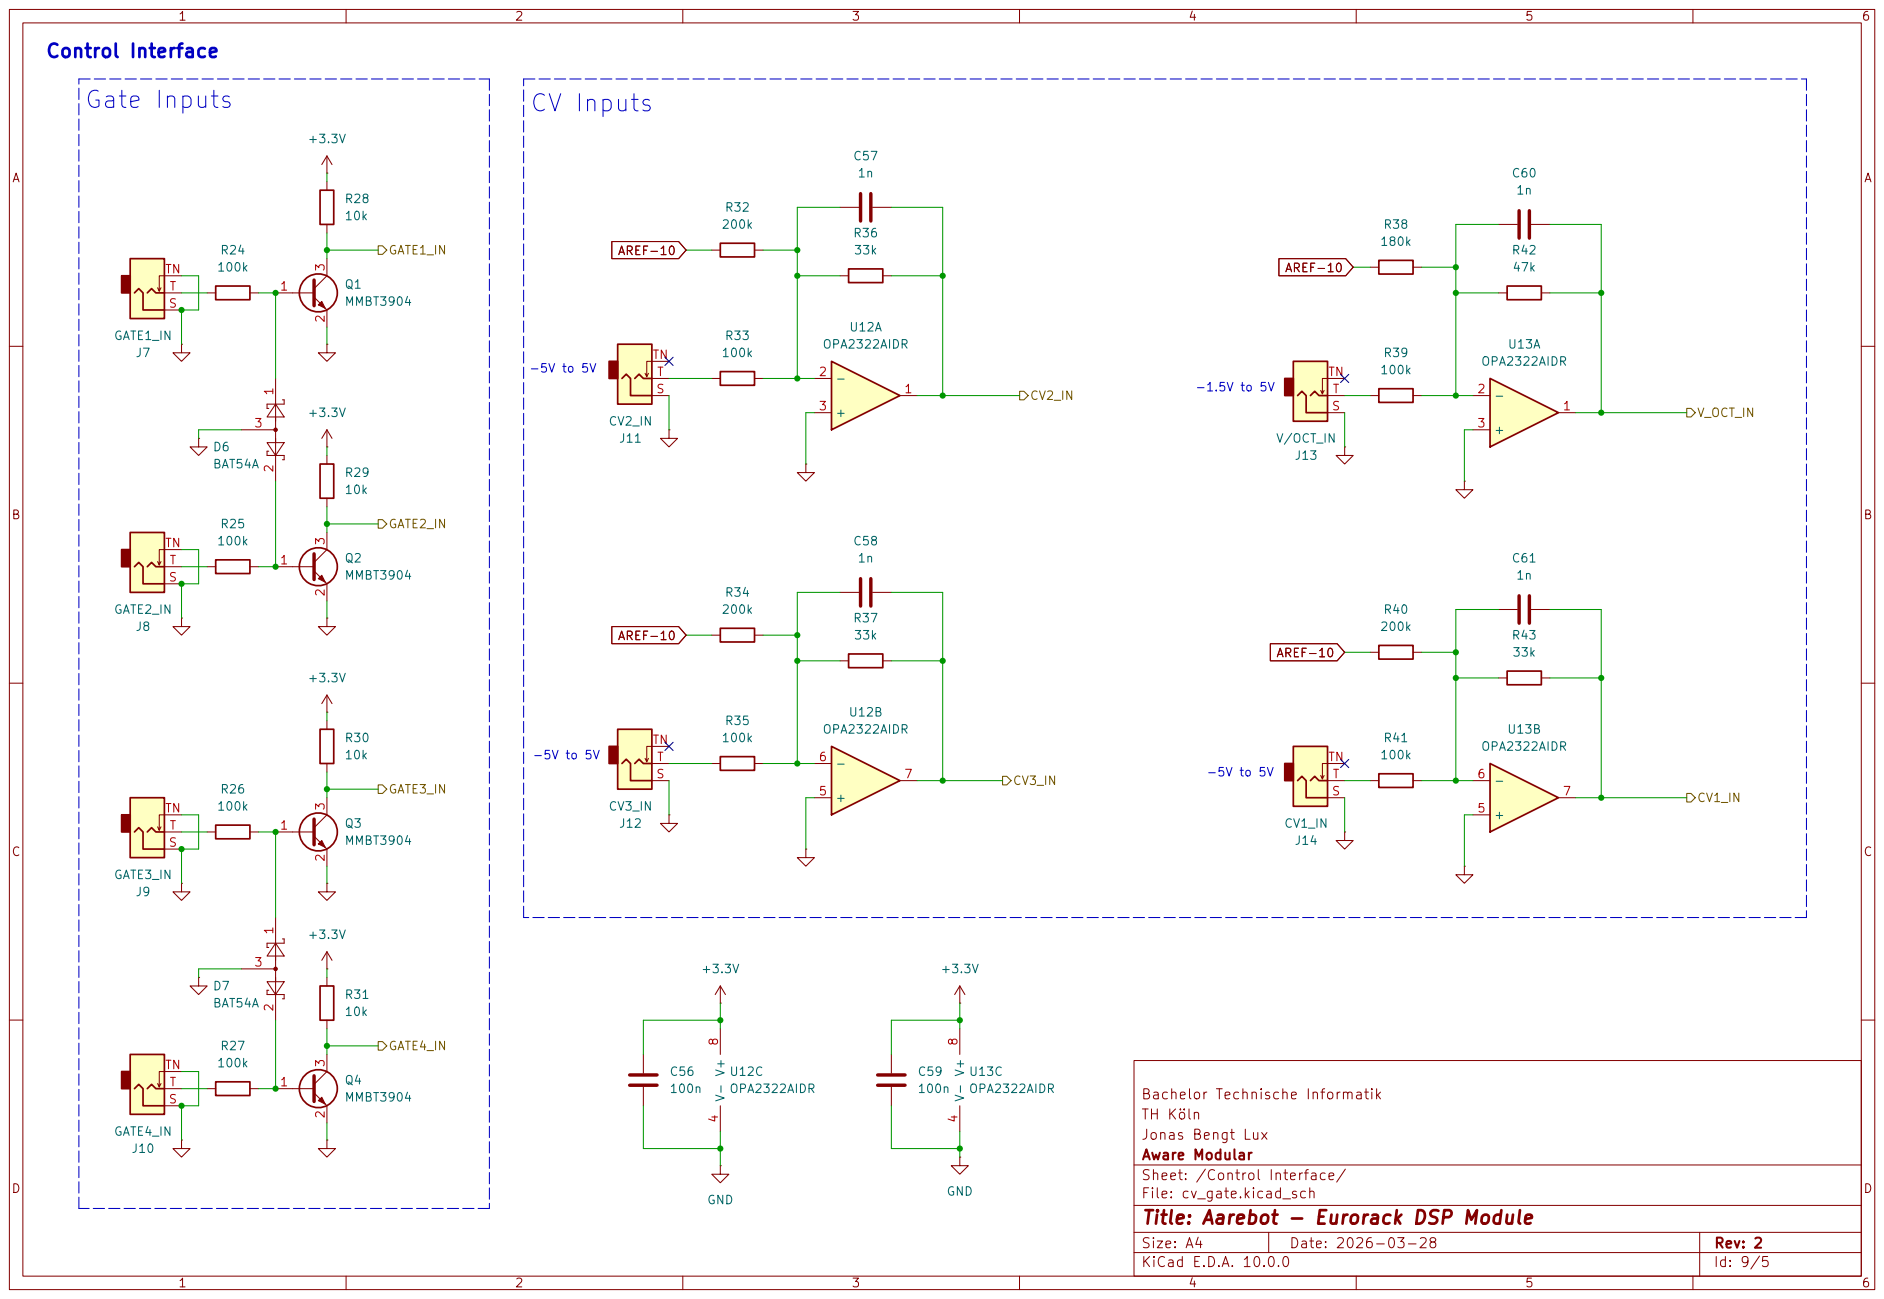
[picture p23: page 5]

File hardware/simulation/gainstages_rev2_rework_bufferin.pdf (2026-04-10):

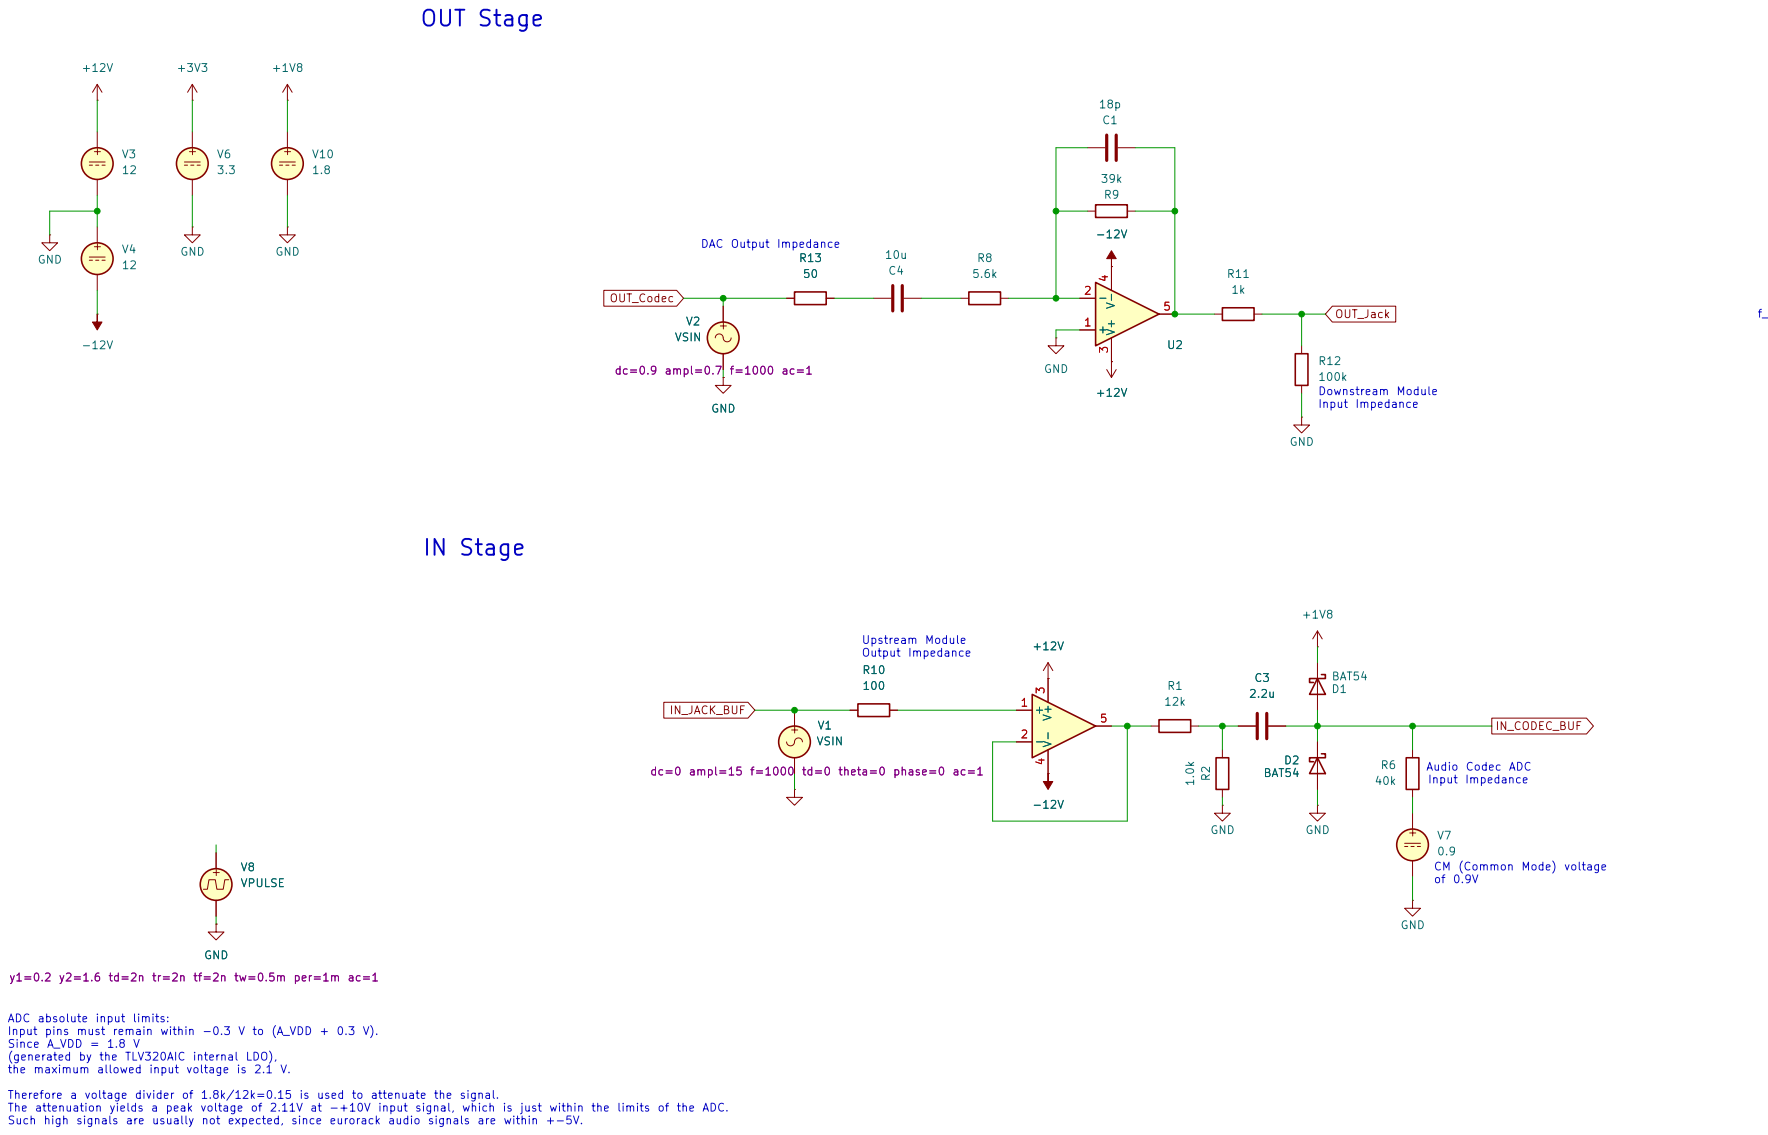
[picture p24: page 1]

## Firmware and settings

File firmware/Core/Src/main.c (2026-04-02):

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
/* Includes ------------------------------------------------------------------*/
#include "main.h"
#include "adc.h"
#include "cmsis_os.h"
#include "dma.h"
#include "gpio.h"
#include "i2c.h"
#include "i2s.h"
#include "tim.h"
#include "usart.h"

/* USER CODE BEGIN Includes */
#include "audioengine.h"
#include "drivers/gpio_driver.h"
#include "drivers/swo_log.h"
#include "drivers/ws2812_driver.h"
#include <stdint.h>

/* USER CODE END Includes */


void SystemClock_Config(void);
void PeriphCommonClock_Config(void);
static void MPU_Config(void);
void MX_FREERTOS_Init(void);
/* USER CODE BEGIN PFP */
void FREERTOS_Init(void);

/* USER CODE END PFP */

/**
  * @brief  The application entry point.
  * @retval int
  */
int main(void) {
    /* USER CODE BEGIN 1 */
    SCB_EnableICache();
    // SCB_EnableDCache();
    /* USER CODE END 1 */

    /* MPU Configuration--------------------------------------------------------*/
    MPU_Config();

    /* MCU Configuration--------------------------------------------------------*/

    /* Reset of all peripherals, Initializes the Flash interface and the Systick. */
    HAL_Init();

    /* USER CODE BEGIN Init */
    // Set NVIC priority grouping so that all interrupt priority bits
    // are treated as preemption priority bits (no subpriority bits).
    // FreeRTOS uses BASEPRI to mask interrupts below
    // configMAX_SYSCALL_INTERRUPT_PRIORITY during FromISR API calls.
    // If the grouping is wrong, BASEPRI is not applied and accessing
    // kernel objects (like queues) from an ISR can cause BusFaults.
    // HAL_NVIC_SetPriorityGrouping(NVIC_PRIORITYGROUP_4);
    /* USER CODE END Init */

    /* Configure the system clock */
    SystemClock_Config();

    /* Configure the peripherals common clocks */
    PeriphCommonClock_Config();

    /* Initialize all configured peripherals */
    MX_GPIO_Init();
    MX_DMA_Init();
    MX_ADC1_Init();
    MX_ADC2_Init();
    MX_I2C1_Init();
    MX_UART4_Init();
    MX_I2S1_Init();
    MX_TIM1_Init();
    MX_TIM12_Init();
    MX_TIM15_Init();
    MX_TIM17_Init();
    MX_TIM13_Init();
    MX_TIM14_Init();
    /* USER CODE BEGIN 2 */
#ifdef CONFIG_DEBUG_LOGS
    ITM_Init();
#endif
    // // fill sinetable
    // initSineTable();

    // generateSineWave(440);

    /* USER CODE END 2 */

    /* Init scheduler */
    osKernelInitialize(); /* Call init function for freertos objects (in cmsis_os2.c) */
    MX_FREERTOS_Init();

    /* Start scheduler */
    osKernelStart();

    /* We should never get here as control is now taken by the scheduler */

    /* Infinite loop */
    /* USER CODE BEGIN WHILE */
    while (1) {
        /* USER CODE END WHILE */

        /* USER CODE BEGIN 3 */
    }
    /* USER CODE END 3 */
}

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
/* MPU Configuration */

void MPU_Config(void) {
    MPU_Region_InitTypeDef MPU_InitStruct = {0};

    /* Disables the MPU */
    HAL_MPU_Disable();

    /** Initializes and configures the Region and the memory to be protected
  */
    MPU_InitStruct.Enable = MPU_REGION_ENABLE;
    MPU_InitStruct.Number = MPU_REGION_NUMBER0;
    MPU_InitStruct.BaseAddress = 0x0;
    MPU_InitStruct.Size = MPU_REGION_SIZE_4GB;
    MPU_InitStruct.SubRegionDisable = 0x87;
    MPU_InitStruct.TypeExtField = MPU_TEX_LEVEL0;
    MPU_InitStruct.AccessPermission = MPU_REGION_NO_ACCESS;
    MPU_InitStruct.DisableExec = MPU_INSTRUCTION_ACCESS_DISABLE;
    MPU_InitStruct.IsShareable = MPU_ACCESS_SHAREABLE;
    MPU_InitStruct.IsCacheable = MPU_ACCESS_NOT_CACHEABLE;
    MPU_InitStruct.IsBufferable = MPU_ACCESS_NOT_BUFFERABLE;

    HAL_MPU_ConfigRegion(&MPU_InitStruct);

    /** Initializes and configures the Region and the memory to be protected
  */
    MPU_InitStruct.Number = MPU_REGION_NUMBER1;
    MPU_InitStruct.BaseAddress = 0x08FFF80C;
    MPU_InitStruct.Size = MPU_REGION_SIZE_2MB;
    MPU_InitStruct.SubRegionDisable = 0x0;
    MPU_InitStruct.AccessPermission = MPU_REGION_FULL_ACCESS;
    MPU_InitStruct.DisableExec = MPU_INSTRUCTION_ACCESS_ENABLE;
    MPU_InitStruct.IsShareable = MPU_ACCESS_NOT_SHAREABLE;

    HAL_MPU_ConfigRegion(&MPU_InitStruct);
    /* Enables the MPU */
    HAL_MPU_Enable(MPU_PRIVILEGED_DEFAULT);
}

/**
  * @brief  Period elapsed callback in non blocking mode
  * @note   This function is called  when TIM7 interrupt took place, inside
  * HAL_TIM_IRQHandler(). It makes a direct call to HAL_IncTick() to increment
  * a global variable "uwTick" used as application time base.
  * @param  htim : TIM handle
  * @retval None
  */
void HAL_TIM_PeriodElapsedCallback(TIM_HandleTypeDef* htim) {
    if (htim->Instance == TIM7) {
        HAL_IncTick();
    }
    /* USER CODE BEGIN Callback 1 */
    // WS2812 Animation timer
    if (htim->Instance == TIM17) {
        ws2812_timer_callback(htim);
    }
    // ws2812 PWM
    if (htim->Instance == TIM15) {
        volatile uint32_t breakpoint = 0;
    }

    // Fader LEDs
    if (htim->Instance == TIM12 || htim->Instance == TIM1) {
        volatile uint32_t breakpoint = 0;
    }

    // button debounces
    if (htim->Instance == TIM13) {
        HAL_TIM_Base_Stop_IT(htim);
        button_debounce_timer_callback(htim);
    } else if (htim->Instance == TIM14) {
        HAL_TIM_Base_Stop_IT(htim);
        button_debounce_timer_callback(htim);
    }
    /* USER CODE END Callback 1 */
}

/**
  * @brief  This function is executed in case of error occurrence.
  * @retval None
  */
void Error_Handler(void) {
    /* USER CODE BEGIN Error_Handler_Debug */
    /* User can add his own implementation to report the HAL error return state */
    __disable_irq();
    while (1) {
    }
    /* USER CODE END Error_Handler_Debug */
}
#ifdef USE_FULL_ASSERT
/**
  * @brief  Reports the name of the source file and the source line number
  *         where the assert_param error has occurred.
  * @param  file: pointer to the source file name
  * @param  line: assert_param error line source number
  * @retval None
  */
void assert_failed(uint8_t* file, uint32_t line) {
    /* USER CODE BEGIN 6 */
    /* User can add his own implementation to report the file name and line number,
     ex: printf("Wrong parameters value: file %s on line %d\r\n", file, line) */
    /* USER CODE END 6 */
}
#endif /* USE_FULL_ASSERT */

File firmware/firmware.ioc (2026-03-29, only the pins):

Mcu.UserName=STM32H7A3RITx
PA0.Signal=UART4_TX
PA1.Signal=UART4_RX
PA10.GPIO_Label=BUTTON1_IN
PA10.Signal=GPXTI10
PA11.GPIO_Label=BUTTON2_IN
PA11.Signal=GPXTI11
PA13.Signal=DEBUG_JTMS-SWDIO
PA14.Signal=DEBUG_JTCK-SWCLK
PA4.Signal=I2S1_WS
PA5.Signal=I2S1_CK
PA7.GPIO_Label=FADER1_IN
PA7.Signal=ADCx_INP7
PA8.GPIO_Label=GATE2_IN
PA8.Signal=GPXTI8
PA9.GPIO_Label=GATE1_IN
PA9.Signal=GPXTI9
PB0.GPIO_Label=FADER3_IN
PB0.Signal=ADCx_INP9
PB1.GPIO_Label=FADER4_IN
PB1.Signal=ADCx_INP5
PB12.GPIO_Label=FAD_LED4_OUT
PB12.Signal=GPIO_Output
PB13.GPIO_Label=FAD_LED3_OUT
PB13.Signal=TIM1_CH1N
PB14.GPIO_Label=FAD_LED2_OUT
PB14.Signal=S_TIM12_CH1
PB15.GPIO_Label=FAD_LED1_OUT
PB15.Signal=S_TIM12_CH2
PB3.Signal=DEBUG_JTDO-SWO
PB4.Signal=I2S1_SDI
PB5.Signal=I2S1_SDO
PB6.Signal=I2C1_SCL
PB7.Signal=I2C1_SDA
PC0.GPIO_Label=V/OCT_IN
PC0.Signal=ADCx_INP10
PC1.GPIO_Label=CV1_IN
PC1.Signal=ADCx_INP11
PC12.GPIO_Label=RGB_LED_DATA
PC12.Signal=S_TIM15_CH1
PC2.GPIO_Label=CV2_IN
PC2.Signal=ADCx_INP12
PC3.GPIO_Label=CV3_IN
PC3.Signal=ADCx_INP13
PC4.Signal=I2S1_MCK
PC5.GPIO_Label=FADER2_IN
PC5.Signal=ADCx_INP8
PC6.GPIO_Label=GATE3_IN
PC6.Signal=GPXTI6
PC7.GPIO_Label=GATE4_IN
PC7.Signal=GPXTI7
PH0-OSC_IN.Signal=RCC_OSC_IN
PH1-OSC_OUT.Signal=RCC_OSC_OUT

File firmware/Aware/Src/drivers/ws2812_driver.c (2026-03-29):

/**
 * @file ws2812_driver.c
 * @brief WS2812B PWM/DMA encoding and animation state machine.
 */
#include "FreeRTOS.h"
#include "stm32h7xx_hal.h"
#include "stm32h7xx_hal_gpio.h"
#include "task.h"

#include "drivers/ws2812_driver.h"
#include "main.h"
#include "project_config.h"
#include "rtos.h"
#include "ws2812_animations.h"

struct ws2812_led_state {
    struct ws2812_color color;       // target color
    ws2812_mode_t mode;              // OFF / STATIC / TRIGGER / ANIMATION
    uint32_t timeout_ticks;          // for trigger mode
    struct led_animation* anim;      // optional animation for this LED
    struct led_animation* next_anim; // optional animation for this LED
    uint32_t anim_tick;              // current tick in animation stage
    uint32_t anim_stage;             // current stage index
};

struct ws2812_mode_state {
    struct ws2812_led_state leds[WS2812_LED_COUNT]; // per-LED state

    bool off_initialized;
};

struct ws2812_config {
    TIM_HandleTypeDef* htim_anim;
    TIM_HandleTypeDef* htim_pwm;
    uint32_t tim_channel_pwm;

    struct ws2812_mode_state state;
    TaskHandle_t userIfTaskHandle;
};

// PWM = 280 MHz / ((PSC + 1) * (ARR + 1)) = 800 kHz
// with PSC of 0 -> ARR + 1 = ( 280 MHz / 800 kHz ) = 350 -> ARR = 349

// Software timer (TIM17) for animation. Cyclic mode.
// f_TIM17 = 280 MHz / (PSC + 1) = 280 MHz / 51 = 5.490 MHz
// ARR reg -> f = 120 Hz <=> p = 8.333 ms
// ARR = (5.490 MHz / 120) - 1 = 45749 ; PSC = 50

#define TIM_PERIOD 350
#define WS2812_BITS_PER_LED 24
#define WS2812_RESET_SLOTS 50                // >50 µs low
#define WS2812_T0H ((TIM_PERIOD * 33) / 100) // ~0.35 µs
#define WS2812_T1H ((TIM_PERIOD * 66) / 100) // ~0.7 µs
#define WS2812_BRIGHTNESS 170

DMA_BUFFER static uint16_t ws2812_pwm_buf[2][WS2812_LED_COUNT * WS2812_BITS_PER_LED + WS2812_RESET_SLOTS];
static uint8_t buf_active = 0; // index of DMA buffer in use
static uint8_t buf_write = 1;  // index of buffer we can write to safely
static struct ws2812_config ws2812_config;

void ws2812_init(const ws2812_init_t* init_cfg) {
    if (init_cfg == NULL || init_cfg->htim_anim == NULL || init_cfg->htim_pwm == NULL || init_cfg->default_animation == NULL ||
        init_cfg->userIfTaskHandle == NULL) {
        return;
    }
    //zeroize pwm buffer (idle high at timer output)
    memset(ws2812_pwm_buf, 0, sizeof(ws2812_pwm_buf));

    for (int i = 0; i < WS2812_LED_COUNT; i++) {
        ws2812_config.state.leds[i].color.r = 0;
        ws2812_config.state.leds[i].color.g = 0;
        ws2812_config.state.leds[i].color.b = 0;

        ws2812_config.state.leds[i].mode = WS2812_MODE_OFF;
        ws2812_config.state.leds[i].timeout_ticks = 0;

        ws2812_config.state.leds[i].anim = NULL;
        ws2812_config.state.leds[i].anim_tick = 0;
        ws2812_config.state.leds[i].anim_stage = 0;

        ws2812_config.state.leds[i].anim = init_cfg->default_animation;
    }

    ws2812_config.htim_anim = init_cfg->htim_anim;
    ws2812_config.htim_pwm = init_cfg->htim_pwm;
    ws2812_config.tim_channel_pwm = init_cfg->tim_channel_pwm;
    ws2812_config.userIfTaskHandle = init_cfg->userIfTaskHandle;
}

// helper to get current write buffer
static uint16_t* get_write_buf(void) {
    return ws2812_pwm_buf[buf_write];
}

// helper to get current DMA buffer
static uint16_t* get_dma_buf(void) {
    return ws2812_pwm_buf[buf_active];
}

// swap buffers after writing
static void swap_buffers(void) {
    uint8_t tmp = buf_active;
    buf_active = buf_write;
    buf_write = tmp;
}

/* ----- Internal API ----- */
void ws2812_start() {
    swap_buffers();
    // start anim timer
    HAL_TIM_Base_Start_IT(ws2812_config.htim_anim);
    for (int i = 0; i < WS2812_LED_COUNT; i++) {
        struct ws2812_color color = {0, 0, 0};
        ws2812_set_static_color(i, color);
    }
}

void ws2812_show(TIM_HandleTypeDef* htim, uint32_t channel) {
    // swap write buffer to DMA
    swap_buffers();

    // start DMA with the active buffer
    HAL_TIM_PWM_Start_DMA(htim, channel, (uint32_t*) get_dma_buf(), sizeof(ws2812_pwm_buf[0]) / sizeof(uint16_t));
}

// sets led in pwm buf based on color values (0..255)
void ws2812_set_led(uint32_t idx, uint8_t r, uint8_t g, uint8_t b) {
    uint32_t i = idx * WS2812_BITS_PER_LED;
    uint32_t color;

    // apply global dampening
    r = (r * WS2812_BRIGHTNESS) / 255;
    g = (g * WS2812_BRIGHTNESS) / 255;
    b = (b * WS2812_BRIGHTNESS) / 255;

    color = (g << 16) | (r << 8) | b;

    uint16_t* buf = get_write_buf();

    for (int bit = 23; bit >= 0; bit--) {
        buf[i++] = (color & (1 << bit)) ? WS2812_T1H : WS2812_T0H;
    }
}

void ws2812_run_step(void) {
    for (int i = 0; i < WS2812_LED_COUNT; i++) {
        struct ws2812_led_state* led = &ws2812_config.state.leds[i];

        switch (led->mode) {
        case WS2812_MODE_OFF:
            ws2812_set_led(i, 0, 0, 0);
            break;
        case WS2812_MODE_STATIC:
            ws2812_set_led(i, led->color.r, led->color.g, led->color.b);
            break;
        case WS2812_MODE_TRIGGER:
            if (led->timeout_ticks > 0) {
                led->timeout_ticks--;
                ws2812_set_led(i, led->color.r, led->color.g, led->color.b);
            } else {
                led->color.r = 0;
                led->color.g = 0;
                led->color.b = 0;
                led->mode = WS2812_MODE_OFF;
                ws2812_set_led(i, 0, 0, 0);
            }
            break;
        case WS2812_MODE_ANIMATION: {
            struct led_animation* anim = ws2812_config.state.leds[i].anim;

            if (anim->total_stages == 0)
                break;

            uint32_t current_stage_index = ws2812_config.state.leds[i].anim_stage;
            struct led_animation_stage* stage = &anim->stages[current_stage_index];

            struct led_animation_stage empty_stage = {.duration = 0, .leds = {{0, 0, 0}, {0, 0, 0}, {0, 0, 0}, {0, 0, 0}}};
            struct led_animation_stage* next_stage;

            if (current_stage_index + 1 < anim->total_stages) {
                next_stage = &anim->stages[current_stage_index + 1];
            } else if (anim->duration == 0) {
                // looping, wrap to first stage
                next_stage = &anim->stages[0];
            } else {
                // non-looping, fade to black
                next_stage = &empty_stage;
            }

            struct ws2812_color a = stage->leds[i];
            struct ws2812_color b = next_stage->leds[i];

            // fixed step size per tick (0..255)
#define LERP_STEP 64
            uint8_t r = a.r + ((int32_t) (b.r - a.r) * LERP_STEP) / 256;
            uint8_t g = a.g + ((int32_t) (b.g - a.g) * LERP_STEP) / 256;
            uint8_t bl = a.b + ((int32_t) (b.b - a.b) * LERP_STEP) / 256;

            ws2812_set_led(i, r, g, bl);

            // Advance time
            led->anim_tick++;
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

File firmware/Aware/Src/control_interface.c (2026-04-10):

/**
 * @file control_interface.c
 * @brief CV input processing, V/Oct pitch scaling, and XY effect parameter routing.
 */
#include "string.h"
#include <FreeRTOS.h>
#include <queue.h>
#include <stdint.h>

#include "control_interface.h"
#include "drivers/adc_driver.h"
#include "drivers/gpio_driver.h"
#include "drivers/ws2812_driver.h"
#include "param_cache.h"
#include "project_config.h"
#include "ws2812_animations.h"
#include "xy_mapper.h"

struct control_interface_config {
    uint16_t adc_cv_working_buf[NUM_CV_CHANNELS];

    TaskHandle_t userIfTaskHandle;

    ADC_HandleTypeDef* hadc_cvs;

    struct calibration_data* calib_data;

    struct cv_in cv_ins[NUM_CV_CHANNELS];
};

static struct control_interface_config control_interface_cfg;

int init_control_interface(struct calibration_data* calib_data, TaskHandle_t userIfTaskHandle, ADC_HandleTypeDef* hadc_cvs) {
    if (hadc_cvs == NULL || userIfTaskHandle == NULL || calib_data == NULL)
        return -1;

    control_interface_cfg.userIfTaskHandle = userIfTaskHandle;
    control_interface_cfg.hadc_cvs = hadc_cvs;
    control_interface_cfg.calib_data = calib_data;

    return 0;
}

int start_control_interface() {
    // implement something else later if needed
    return 0;
}

void control_interface_process() {
    int res = adc_copy_cv_to_working_buf(control_interface_cfg.adc_cv_working_buf, NUM_CV_CHANNELS);
    if (res != 0) {
        // skip processing if samples cant be fetched.
        return;
    };

    for (size_t i = 0; i < NUM_CV_CHANNELS; i++) {
        float v = float_value(control_interface_cfg.adc_cv_working_buf[i]);
        control_interface_cfg.cv_ins[i].val = v;
    }

    /* ----- V/Oct CV In ----- */
    float v_oct_normalized = control_interface_cfg.cv_ins[CV_V_OCT].val;    // 0..1
    float pitch_scale = control_interface_cfg.calib_data->voct_pitch_scale; // pitch_scale = semitones per normalized CV unit
    float pitch_offset = control_interface_cfg.calib_data->voct_pitch_offset;

    float semitones = v_oct_normalized * pitch_scale + pitch_offset; // apply offset and scale from calibration
    float pitch_factor_new = powf(2.0f, semitones / 12.0f); // equal temperament: 2^(n/12) doubles frequency each octave (12 semitones)
    param_cache_set_pitch_cv(pitch_factor_new);

    /* ----- Slice Position CV In ----- */
    // TODO: there is a logic problem here.
    // ADC gives a bipolar signal. slice 0 cant be -5V, since when no cable is plugged in we want slice 0.
    // Best way to do this is to hardware design gpio read, to detect if cable is plugged in.
    // if no cable is plugged in, set offset to 0 so that slice pos is 0. if cable is plugged in, set offset to calibrated value (0.5) so that full range of slice pos is available.
    float val = control_interface_cfg.cv_ins[CV_SLICE_POS].val;
    float offset = control_interface_cfg.calib_data->cv_offset[CV_SLICE_POS];
    // for now ignore negative ADC readings, and map positive to full 0..1 range.
    float slice_pos = (offset - val) * 2; // 0..1
    slice_pos = fmaxf(0.0f, fminf(1.0f, slice_pos));
    param_cache_set_slice_pos(slice_pos);

    /* ------ XY XV Plane ------ */
    // Read raw CV and subtract calibration offset
    float val_x = control_interface_cfg.cv_ins[CV_X].val;
    float offset_x = control_interface_cfg.calib_data->cv_offset[CV_X];
    val_x -= offset_x;

    float val_y = control_interface_cfg.cv_ins[CV_Y].val;
    float offset_y = control_interface_cfg.calib_data->cv_offset[CV_Y];
    val_y -= offset_y;

    // Invert because of hardware inverting op-amps
    val_x = -val_x;
    val_y = -val_y;

    // Map from 0..1 (after offset) to -1..1
    float norm_x = val_x * 2.0f; // if offset already made center 0
    float norm_y = val_y * 2.0f;

    // Clamp to [-1, 1] just in case
    norm_x = fmaxf(-1.0f, fminf(1.0f, norm_x));
    norm_y = fmaxf(-1.0f, fminf(1.0f, norm_y));

    xy_mapper_update(norm_x, norm_y);
}

// 2-point V/Oct calibration routine.
// Inspired by the calibration approach observed in the Mutable Instruments Clouds firmware
// (https://github.com/pichenettes/eurorack), though this is a standard ADC 2-point calibration technique.
// C1 should be 1V
// returns normalized C1 value (0..1) to be used as reference for C3 calibration and pitch calculations
float calibrate_C1() {
    uint16_t working_buf[NUM_CV_CHANNELS];
    adc_copy_cv_to_working_buf(working_buf, NUM_CV_CHANNELS);
    uint16_t adc_val = working_buf[ADC_V_OCT_CV];
    return float_value(adc_val);
}

// read and store offsets for all CV channels
// input 0V here, so that it can be subtracted from future readings to get 0-centered CV values
void calibrate_offsets(struct calibration_data* calib_data) {
    uint16_t working_buf[NUM_CV_CHANNELS];
    adc_copy_cv_to_working_buf(working_buf, NUM_CV_CHANNELS);
    for (size_t i = 0; i < NUM_CV_CHANNELS; ++i) {
        uint16_t adc_val = working_buf[i];
        calib_data->cv_offset[i] = float_value(adc_val);
    }
}

// C3 should be 3V
int calibrate_C3(struct calibration_data* calib_data, float c1) {
    uint16_t working_buf[NUM_CV_CHANNELS];
    adc_copy_cv_to_working_buf(working_buf, NUM_CV_CHANNELS);
    uint16_t adc_val = working_buf[ADC_V_OCT_CV];
    float c3 = float_value(adc_val);
    float delta = c3 - c1;

    if (delta > -0.5f && delta < -0.0f) {
        calib_data->voct_pitch_scale = 24.0f / delta;
        calib_data->voct_pitch_offset = 12.0f - (calib_data->voct_pitch_scale * c1);
        return 0;
    } else {
        // invalid calibration, delta too small or too large
        return -1;
    }
}

// this is run from user interface task, so it can use button states and ws2812 animations for feedback
int control_interface_calibrate_voct(struct calibration_data* calib_data) {
    // procedure:
    // 1. input C1 voltage, then wait for button press to store C1
    if (!wait_for_both_buttons_pushed())
        return -1;
    float c1 = calibrate_C1();
    ws2812_change_animation_all(&anim_setting_step_confirmed);
    ws2812_change_animation_all(&anim_breathe_led1);
    wait_for_both_buttons_released();

    // 2. input C3 voltage, then wait for button press to store C3 and compute scale/offset
    if (!wait_for_both_buttons_pushed())
        return -1;
    int res = calibrate_C3(calib_data, c1);
    if (res != 0) {
        return -1;
    }
    ws2812_change_animation_all(&anim_setting_step_confirmed);
    ws2812_change_animation_all(&anim_breathe_led2);
    wait_for_both_buttons_released();

    // 3. remove all cables and wait for button press to store offsets (assuming 0V input, so that it can be subtracted from future readings to get 0-centered CV values)
    if (!wait_for_both_buttons_pushed())
        return -1;
    calibrate_offsets(calib_data);
    wait_for_both_buttons_released();
    ws2812_change_animation_all(&anim_setting_confirmed);

    return res;
}

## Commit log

2024-07-21 add hardware-design
    [audio_codec.kicad_sch, ima_new_codec.kicad_pcb, ima_new_codec.kicad_sch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]
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2024-07-21 changes to input/output stages
    [audio_codec.kicad_sch, ima_new_codec.kicad_sch, in_outs.kicad_sch]
2024-07-21 changes to in/out stages
    [audio_codec.kicad_sch, ima_new_codec.kicad_sch, in_outs.kicad_sch]
2024-08-06 changes to hardware design
    [audio_codec.kicad_sch, ima_new_codec.kicad_sch, in_outs.kicad_sch]
2024-10-15 changes to schematic
    [audio_codec.kicad_sch, ima_new_codec.kicad_sch, in_outs.kicad_sch]
2025-01-12 migrate to stm32h7 mcu
    [audio_codec.kicad_sch, aware01_h7.kicad_pcb, aware01_h7.kicad_sch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]
2025-01-14 update schematic
    [audio_codec.kicad_sch, aware01_h7.kicad_pcb, aware01_h7.kicad_sch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]
2025-01-16 refine schematic
    [audio_codec.kicad_sch, aware01_h7.kicad_sch, controls.kicad_sch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]
2025-01-16 remove old kicad project
    [audio_codec.kicad_sch, controls.kicad_sch, cv_gate.kicad_sch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]
2025-01-16 assign footprints
    [aware01_h7.kicad_sch, controls.kicad_sch, cv_gate.kicad_sch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]
2025-01-16 change jack symbols
    [aware01_h7.kicad_pcb, aware01_h7.kicad_sch, controls.kicad_sch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]
2025-01-27 update pcb
    [audio_codec.kicad_sch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]
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2025-01-27 minor layout adjustments
    [aware01_h7.kicad_pcb]
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2025-01-28 change PWR to GND plane and reroute 3V3
    [audio_codec.kicad_sch, aware01_h7.kicad_sch, aware01_h7_rev1.kicad_pcb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]
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2025-01-29 add series termination resistors
    [aware01_h7.kicad_pcb, aware01_h7_rev2.0.kicad_sch, term_resistance_sim.kicad_pcb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]
2025-01-31 update to rev 1.2
    [audio_codec.kicad_sch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]
2025-02-03 rework layout and insert eletrolytic caps for gainstages
    [audio_codec.kicad_sch, aware01_h7_rev1_2.kicad_pcb, aware01_h7_rev1_2.kicad_sch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]
2025-02-03 update gainstage simulations
    [gainstages.kicad_sch]
2025-02-04 add 3rd Gate In and add resistor part No's
    [aware01_h7_rev1_2.kicad_pcb, aware01_h7_rev1_2.kicad_sch, controls.kicad_sch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]
2025-03-09 slight changes to layout
    [audio_codec.kicad_sch, aware01_h7_rev1_2.kicad_pcb, aware01_h7_rev1_2.kicad_sch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]
2025-03-10 length matching incl. termination resistors
    [aware01_h7_rev1_2.kicad_pcb, aware01_h7_rev1_2.kicad_sch]
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2025-08-02 add rev2 - migrate to stm32h7a3rit6
    [audio_codec.kicad_sch, aware01_h7.kicad_pcb, aware01_h7.kicad_sch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]
2025-08-02 routing and placement
    [aware01_h7_rev2_0.kicad_pcb]
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2025-08-10 add 5V buck converter
    [audio_codec.kicad_sch, aware01_h7_rev2_0.kicad_pcb, aware01_h7_rev2_0.kicad_sch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]
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2025-08-18 move power schematic to root page
    [power.kicad_sch]
2025-11-06 update pcb with 5V buck converter
    [aware01_h7_rev2_0.kicad_pcb, aware01_h7_rev2_0.kicad_sch]
2025-11-13 refine layout, add testpoints
    [audio_codec.kicad_sch, aware01_h7_rev2_0.kicad_pcb, aware01_h7_rev2_0.kicad_sch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]
2025-11-14 hardware_design: add slide pot filtering
    [aware01_h7_rev2_0.kicad_pcb, controls.kicad_sch]
2025-11-17 hw: update spice simulation rework
    [gainstages_rev2_rework.kicad_sch]
2025-11-17 hw: update hw design
    [aware01_h7_rev2_0.kicad_pcb, aware01_h7_rev2_0.kicad_sch, controls.kicad_sch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]
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2025-11-28 hwardware: update analog stages simulation
    [aware01_h7_rev2_0.kicad_pcb, cv_gate.kicad_sch, gainstages_rev2_rework_bufferin.kicad_sch]
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2025-12-19 hardware: update analog sim and routing (wip)
    [audio_codec.kicad_sch, aware01_h7_rev2_0.kicad_pcb, aware01_h7_rev2_0.kicad_sch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]
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2025-12-19 sim: update simulation schematic and libraries
    [gainstages_rev2_rework_bufferin.kicad_sch]
2025-12-19 hardware: fix clamping diode orientation
    [aware01_h7_rev2_0.kicad_pcb, in_outs.kicad_sch]
2025-12-19 hardware: change clamping reference to codec AVDD
    [audio_codec.kicad_sch, aware01_h7_rev2_0.kicad_pcb, in_outs.kicad_sch]
2025-12-20 hardware: add levelshifter for WS2812
    [aware01_h7_rev2_0.kicad_pcb, aware01_h7_rev2_0.kicad_sch, controls.kicad_sch]
2025-12-28 hardware: adjust buck layout
    [aware01_h7_rev2_0.kicad_pcb, aware01_h7_rev2_0.kicad_sch]
2025-12-29 hardware: switch crystal and calculate load caps
    [aware01_h7_rev2_0.kicad_pcb, aware01_h7_rev2_0.kicad_sch]
2025-12-30 hardware: add GND shielding around crystal
    [aware01_h7_rev2_0.kicad_pcb]
2025-12-30 hardware: remove old led schematic
    [leds.kicad_sch]
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2026-01-05 fix: small fixes in audio engine (WIP)
    [audioengine.c]
2026-01-05 fix: update pinout on .ioc
    [firmware2_1.ioc]
2026-01-09 hw: improve design after design review (WIP)
    [aware01_h7_rev2_0.kicad_pcb, aware01_h7_rev2_0.kicad_sch]
2026-01-09 hw: Improve routing and layouting
    [aware01_h7_rev2_0.kicad_pcb]
2026-01-10 hw: improve layout, update BOM
    [audio_codec.kicad_sch, aware01_h7_rev2_0.kicad_pcb, aware01_h7_rev2_0.kicad_sch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]
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2026-01-12 hw: update BOM and layout
    [audio_codec.kicad_sch, aware01_h7_rev2_0.kicad_pcb, aware01_h7_rev2_0.kicad_sch]
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2026-01-22 fix: add in pitch notification queue
    [control_interface.c, rtos.c]
2026-01-25 feat: add GPIO driver and enable interrupts
    GATE3_IN pin cannot be used as interrupt, since EXTI line is used by
    GATE1_IN. This is a hardware design error and can only be fixed by
    wiring GATE3_IN (PC9) to PC6, wich uses a free EXTI line.
    [firmware.ioc, gpio_driver.c, main.c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]
2026-01-25 hw: add scope screenshots that document buck restart
    Which was caused because of short circuit on the MCU pins.
    When the LDO received voltage above dropout level, the short draws too
    much current and causes the buck to restart.
    [audio_codec.kicad_sch, aware01_h7_rev2_0.kicad_pcb, aware01_h7_rev2_0.kicad_sch]
2026-01-26 fix: fix adc driver init reqs
    [firmware.ioc, rtos.c]
2026-01-26 hw: update tactile switch footprints and BOM entry
    [aware01_h7_rev2_0.kicad_pcb, aware01_h7_rev2_bom_check.csv, controls.kicad_sch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]
2026-01-29 fix: fix audio dma pointer access
    [audioengine.c, gpio_driver.c, main.c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]
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2026-01-31 fix: update pitch calibration (still WIP)
    [control_interface.c, firmware.ioc, main.c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]
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2026-02-05 feat: refactor into fsm structure
    now the main tapeplayer logic is divided into 2 FSMs:
    rec_fsm and play_fsm. This should make following logic easier and
    prevents flag spagheti
    [rtos.c]
2026-02-05 fix: add correct crossfading to silence
    after sample end is near while playback
2026-02-06 fix: seperate fading for end of pb buffer reached
    [project_config.h]
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2026-02-12 fix: add led array per animation step
    [high_pitched_noise.csv, tape_dump.csv]
2026-02-13 feat: fix and enable read/write persistent settings
    - add magic word for flash validation.
    - refine calibration routine
    [control_interface.c, gpio_driver.c, project_config.h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]
2026-02-16 fix: Bank is now specified when erasing flash sector
    [settings.c]
2026-02-16 fix: refine ws2812 animations
    [control_interface.c, firmware.ioc, gpio_driver.c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]
2026-02-18 feat: lots of changes
    - change in/out buffer fades to Q16 fixed point
    - use oversampling for ADCs (potentiometers and CV ins), to stabilize
    pitch tracking
    - make audio samplerate configurable (24kHz, 48kHz family). This enables
    bigger tape buffer and adds Lofi character
    - refine startup procedure:
    Audio task is hold until calibration is done, or skipped
    - some ws2812 adjustments
    [adc_driver.c, audioengine.c, control_interface.c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]
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2026-02-18 feat: add cyclic and reverse mode
    - also add hw timer based button debouncing
    [adc_driver.c, gpio_driver.c, main.c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]
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2026-02-22 feat: design biquad cascading
    [coeffs.csv]
2026-02-24 feat: add excite and grit based on decimation value
    decimation now can be only in powers of 2. Other values where causing
    pitch drifting. So keep this for now.
    In project_config.h there are now 2 MACROS which define the amount of
    grit (hold amount of downsampled audio) and excite (nonlinear distortion), added depending on decimation value.
    This should compensate for loss of high frequencies when downsampling.
    So in the end we can use downsampling to lenghten our recording buffer,
    at the loss auf audio quality. This is compensated with grit factor
    [coeffs.csv]
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2026-02-24 fix: switch to Q48.16 phase accumulation
    this brings noticeable performance boost, since fraction part is now
    only 16bits long (more than enough). These operations are handled in 1
    cpu cycle on 32bit ARM M7
    [project_config.h, rtos.c]
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2026-02-24 fix: make lut access time consistent
    by removing pitch-aware fade scaling.
    just use a fixed fade length.
    (WIP) cyclic is still clicking a bit. Look into that later
    [project_config.h]
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2026-02-28 fix: adjust ws2812 clock timings to new cpu freq
    [main.c, rtos.c, ws2812_driver.c]
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2026-03-02 fix: GPIO EXTI change to falling edge
    [firmware.ioc, main.c]
2026-03-02 feat: add one-pole lp in rev feedback path
    also adjust mapping of different reverb parameters to XY plane
    [lp_fc2k_but_N2_coeffs.csv]
2026-03-02 fix: add reverse sample lookup while in reverse playback.
    [gpio_driver.c, project_config.h]
2026-03-09 fix: docs and buffer adjustment
    [rtos.c]
2026-03-14 fix: project config setup refinements
    [project_config.h, rtos.c]
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2026-03-16 hardware: increase SW hole clearance
    [aware01_h7_rev2_0_panel-Faceplate.step, aware01_h7_rev2_0_panel.FCStd]
2026-03-16 fix: adjust GPIO Button debounce timers
    [firmware.ioc, gpio_driver.c, ws2812_driver.c]
2026-03-19 fix: ws2812 ISR cleanup and project config adjustments
    ws2812 hardware timer now notifies UI task on elapsed ISR
    [main.c, project_config.h, rtos.c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]
2026-03-19 docs: panel design 3d render
    [aware01_h7_rev2_0_panel.FCStd]
2026-03-22 fix: update TLV input impedance config to 40k
    - increase PGA gain since it is being held down by 40k input impedance
    [audioengine.c, tlv320_driver.c]
2026-03-23 fix: specify TLV processing blocks
    [project_config.h, tlv320_driver.c]
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2026-03-27 chore: panel design file management
    [aware01_h7_rev2_0_panel-Faceplate.step, aware01_h7_rev2_0_panel.FCStd, aware01_h7_rev2_0_pcb_and_panel.obj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]
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2026-03-29 fix: bodge PC6 to PC9 for GPIO EXTI use
    [firmware.ioc, main.c, main.h]
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2026-04-13 fix: reverse playback in cycling mode
    [project_config.h]

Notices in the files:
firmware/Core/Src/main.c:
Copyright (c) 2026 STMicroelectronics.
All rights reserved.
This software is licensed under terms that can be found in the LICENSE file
